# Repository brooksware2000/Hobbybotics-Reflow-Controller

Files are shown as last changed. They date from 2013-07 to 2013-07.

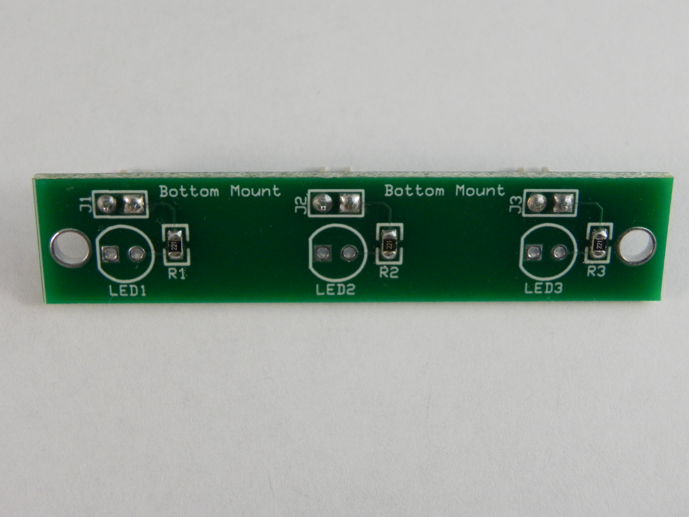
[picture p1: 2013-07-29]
Hardware/Hobbybotics LED Panel/Pictures/DSCN0549.JPG

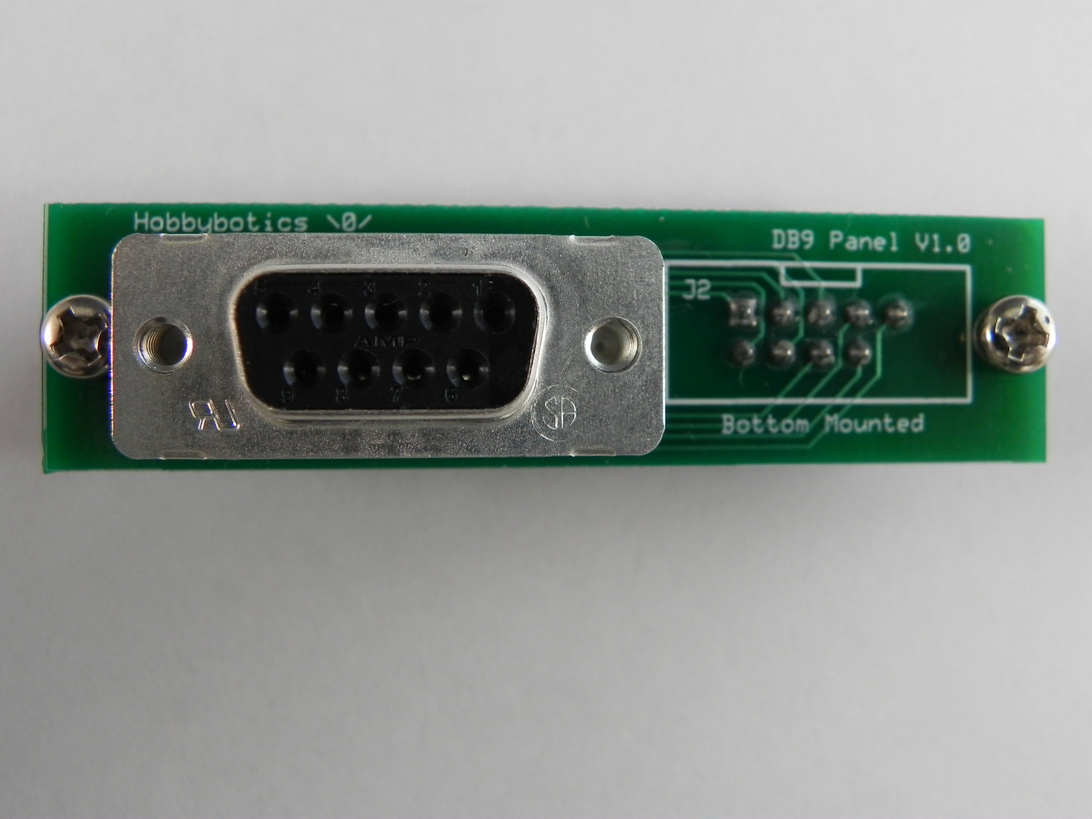
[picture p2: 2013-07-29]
Hardware/Hobbybotics DB9 Panel/Pictures/DSCN0542.JPG

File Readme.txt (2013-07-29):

The following files are for a reflow controller I designed to interface to a
common toaster oven.  The controller implements a PID routine and can be run
in manual mode or interfaced to a PC.

More information about this project can be found at the following links:

http://hobbybotics.com
http://hobbybotics.com/projects/hobbybotics-reflow-controller-v8-03/

28 July 2013 - Uploaded a revision to the firmware.  An error was identified in
the Bake routine which prevented it from working properly.  This has been fixed
in revision 5H.

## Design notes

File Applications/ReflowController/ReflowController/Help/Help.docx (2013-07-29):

Contents
Introduction | ............................................................ | 3
Welcome | ............................................................ | 3
License Agreement | ............................................................ | 3
Copyright and Trademarks | ............................................................ | 3
Application Window | ............................................................ | 4
Control Functions | ............................................................ | 4
Connect Button | ............................................................ | 4
Disconnect Button | ............................................................ | 4
Properties Button | ............................................................ | 4
Auxiliary 1 & 2 Button | ............................................................ | 4
Enable Logging Checkbox | ............................................................ | 5
Clear Data Button | ............................................................ | 5
Save Log File Button | ............................................................ | 5
Port Selection Field | ............................................................ | 5
Baud Rate Selection Field | ............................................................ | 5
Temperature Label | ............................................................ | 5
Set Point Temperature Label | ............................................................ | 5
Stage Remaining Time Label | ............................................................ | 5
Stage Label | ............................................................ | 5
Elapsed Time Label | ............................................................ | 5
Heater label | ............................................................ | 6
Auxiliary 1 Label | ............................................................ | 6
Auxiliary 2 Label | ............................................................ | 6
Log Data Grid | ............................................................ | 6
Log Data Chart | ............................................................ | 6
Menu Options | ............................................................ | 7
File Menu | ............................................................ | 7
View | ............................................................ | 7
Profile | ............................................................ | 7

Contents
Log File | ............................................................ | 8
Chart File | ............................................................ | 9
Chart Image | ............................................................ | 10
Save | ............................................................ | 11
Log File | ............................................................ | 11
Chart File | ............................................................ | 12
Chart Image | ............................................................ | 13
Page Setup | ............................................................ | 14
Print Preview | ............................................................ | 15
Print | ............................................................ | 16
Run Menu | ............................................................ | 17
Calibrate Oven | ............................................................ | 17
Start Reflow | ............................................................ | 18
Start Bake | ............................................................ | 19
Reset Controller | ............................................................ | 20
Configure Menu | ............................................................ | 21
Application Settings | ............................................................ | 21
Configure RTC | ............................................................ | 22
Create/Edit Profile | ............................................................ | 23
Upload Profile | ............................................................ | 24
Update Firmware | ............................................................ | 25
Open Programmer | ............................................................ | 26
Open Editor | ............................................................ | 27
Help Menu | ............................................................ | 28
About | ............................................................ | 28

Introduction

Welcome

The Reflow Controller application is an optional interface for the reflow controller hardware. The software is designed to allow computer control of the reflow controller and log reflow sessions for later viewing and editing.

License Agreement

This agreement shall govern the use of this software by the user of the Software Package. The user is granted the right to use, modify, and redistribute this Software Package as he or she wishes. The developer of this software will not assume any responsibility for the misuse of this software or any damage that may result from use of this software.

Copyright and Trademarks

Hobbybotics reserves the right to modify this license agreement at any time.

Application Window

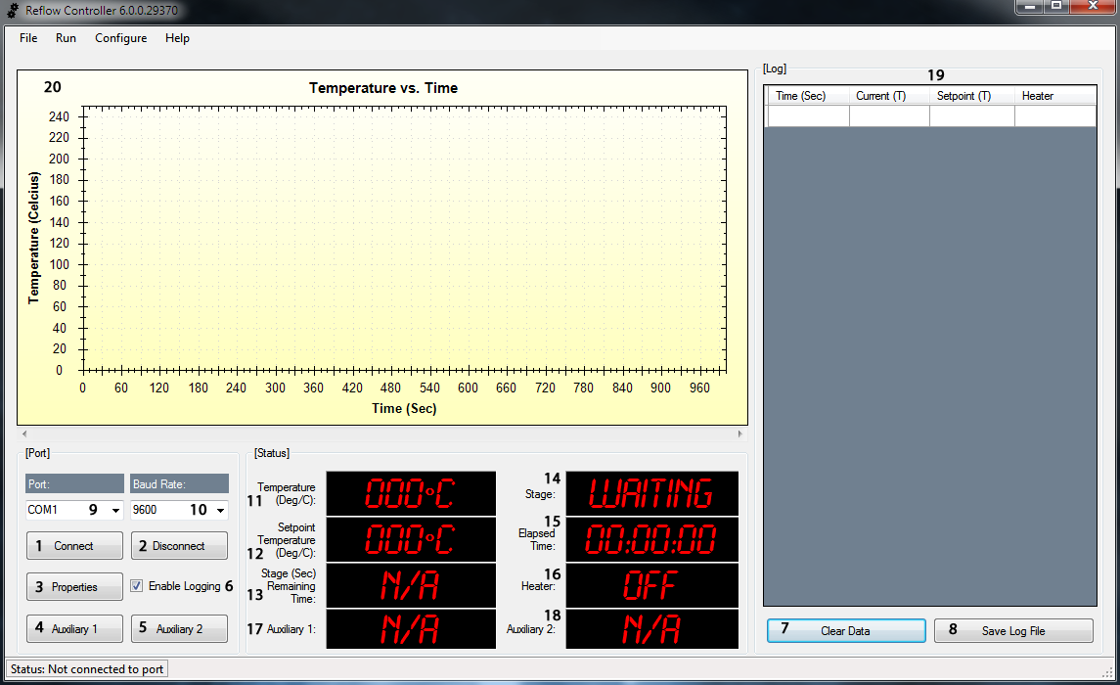
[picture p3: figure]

Control Functions

1. Connect Button

This button establishes a connection to the selected serial port at the selected baud rate if available ports are detected.

2. Disconnect Button

This button disconnects from the serial port.

3. Properties Button

This button opens the device manager applet so that the serial port properties may be viewed or edited.

4. Auxiliary 1 Button

This button will connect or disconnect the device attached to the auxiliary jack.

5. Auxiliary 2 Button

This button will connect or disconnect the device attached to the auxiliary jack.

6. Enable Logging Checkbox

This checkbox will enable or disable data logging.

7. Clear Data Button

This button will clear any data contained in the data grid.

8. Save Log File Button

This button will save a log file of data from the data grid to a file compatible with Microsoft Excel or any Excel compatible spreadsheet. The created file can also be opened with a text editor.

9. Port Selection

This field is loaded with all detected serial ports and allows a port to be selected for connection. The propertied button should be used to ensure the selected port matches the port the reflow controller is connected to.

10. Baud Rate Selection

This field is loaded with available baud rates. The default baud rate for the reflow controller is 9600 baud. The selected baud rate needs to match this setting to ensure proper communication.

11. Temperature Label

This label displays the current temperature measurement.

12. Set Point Temperature Label

This label displays the set point temperature value.

13. Stage Remaining Time Label

This label displays the remaining time for each stage (Preheat, Soak, Heating, Reflow, Cool Down and Bake).

14. Stage Label

This label displays the current stage (Preheat, Soak, Heating, Reflow, Cool Down and Bake).

15. Elapsed Time Label

This label displays the total time the process is taking.

16. Heater Label

This label displays the on/off state of the oven heater relay.

17. Auxiliary 1 Label

This label displays the on/off state of the auxiliary 1 device.

18. Auxiliary 2 Label

This label displays the on/off state of the auxiliary 2 device.

19. Log Data Grid

This data grid captures the time (seconds), current temperature (Celsius), set point temperature (Celsius) and heater on/off state of the reflow process. This data can be exported to an Excel compatible file.

20. Log Data Chart

This graphical chart plots the time (seconds) and current temperature (Celsius) of the reflow process as a line graph. This chart can be saved as an image, saved as a data file or printed.

Menu Options

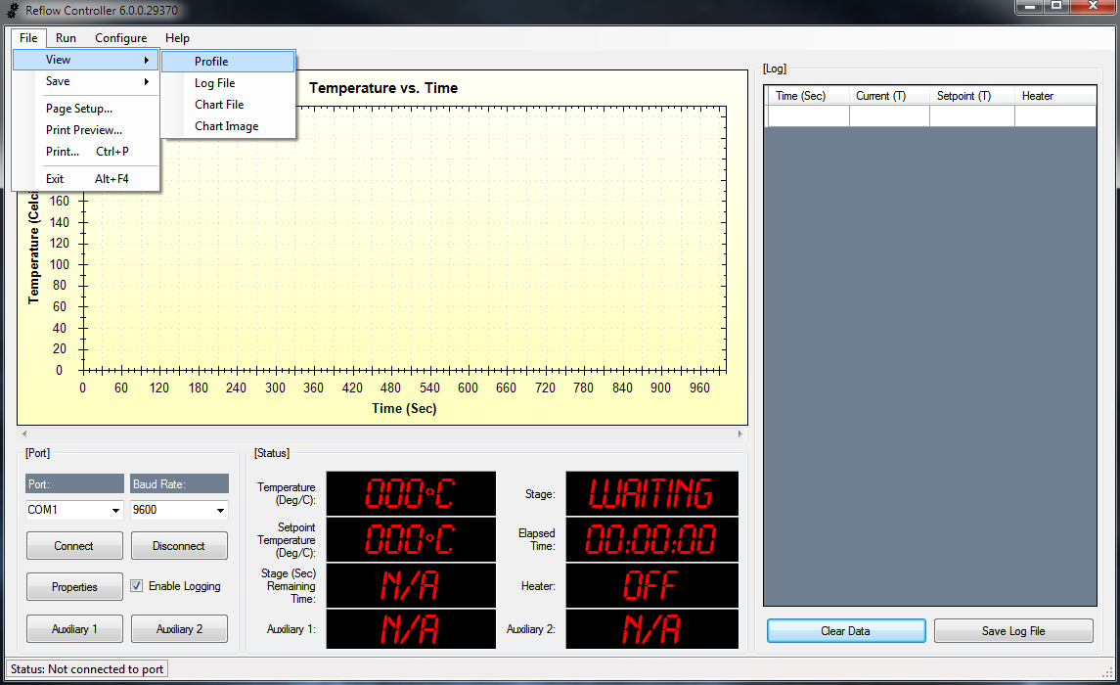
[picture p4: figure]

File Menu

- View Profile

This menu option opens a reflow profile for viewing and editing within the default text editor.

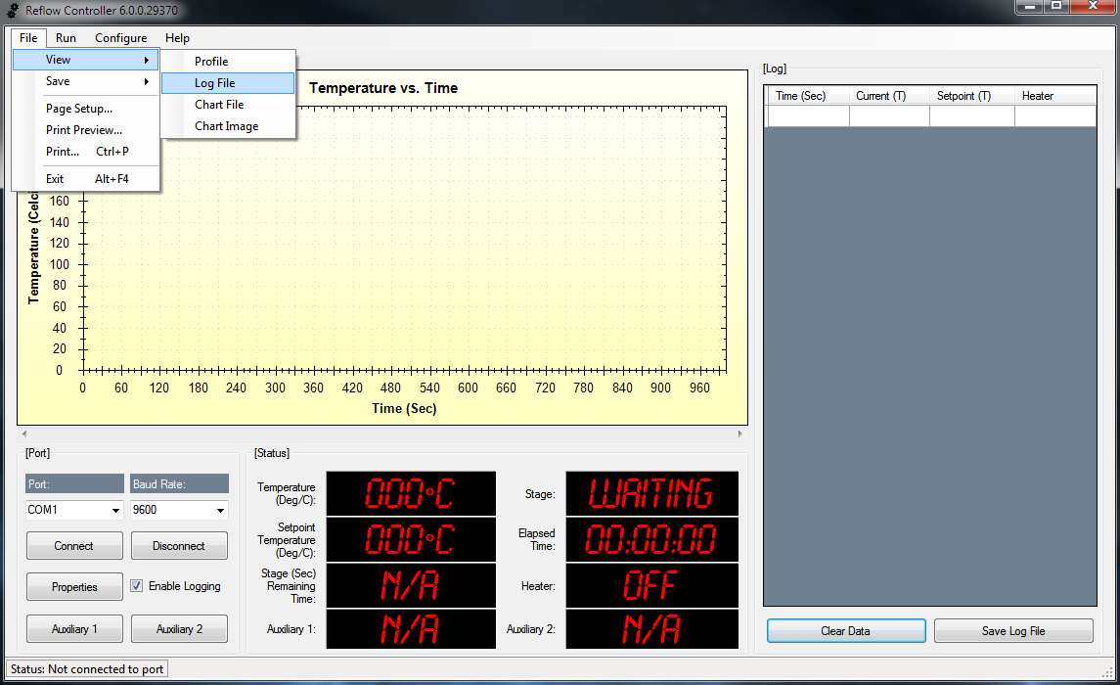
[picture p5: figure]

- View Log File

This menu option opens a log file for viewing and editing within Microsoft Excel. A compatible spreadsheet application or text editor can be used to view and edit a log file.

- View Chart File

This menu option opens a chart file for viewing within the reflow application.

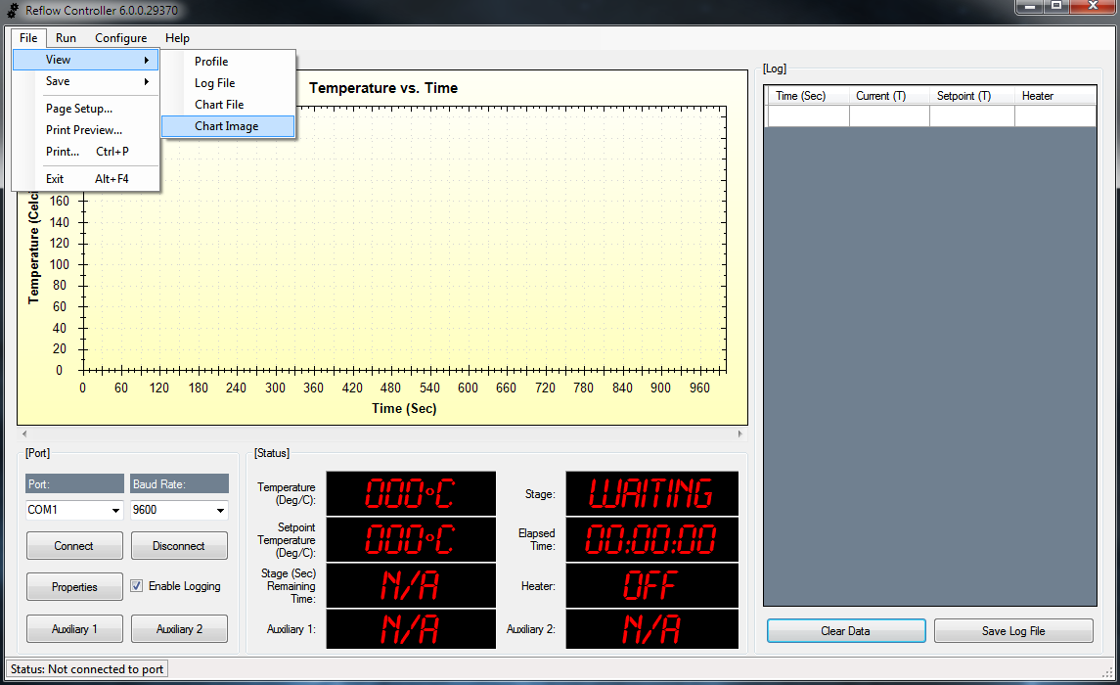
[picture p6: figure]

- View Chart Image

This menu option opens a chart image for viewing and editing with the default image application.

- Save Log File

This menu option saves a reflow session to a log file for viewing and editing in Microsoft Excel. A compatible spreadsheet application or text editor can be used to view and edit a log file.

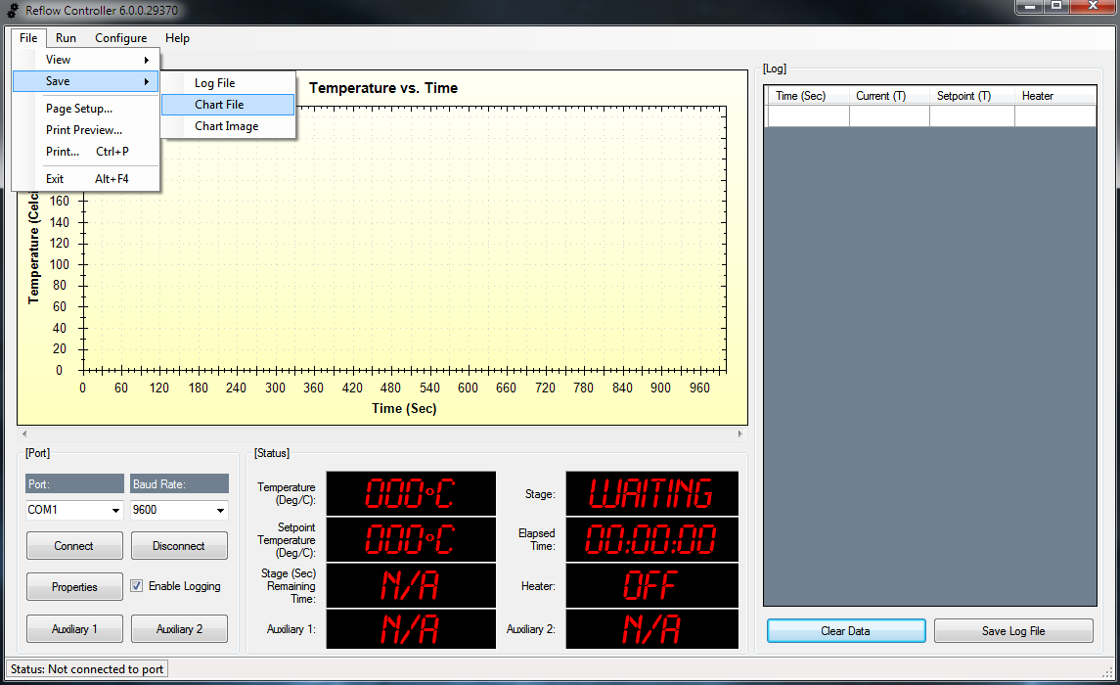
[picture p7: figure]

- Save Chart File

This menu option saves the graphical chart data to a chart file for viewing within the reflow application.

- Save Chart Image

This menu option saves a chart image to a file for viewing and editing with the default image application.

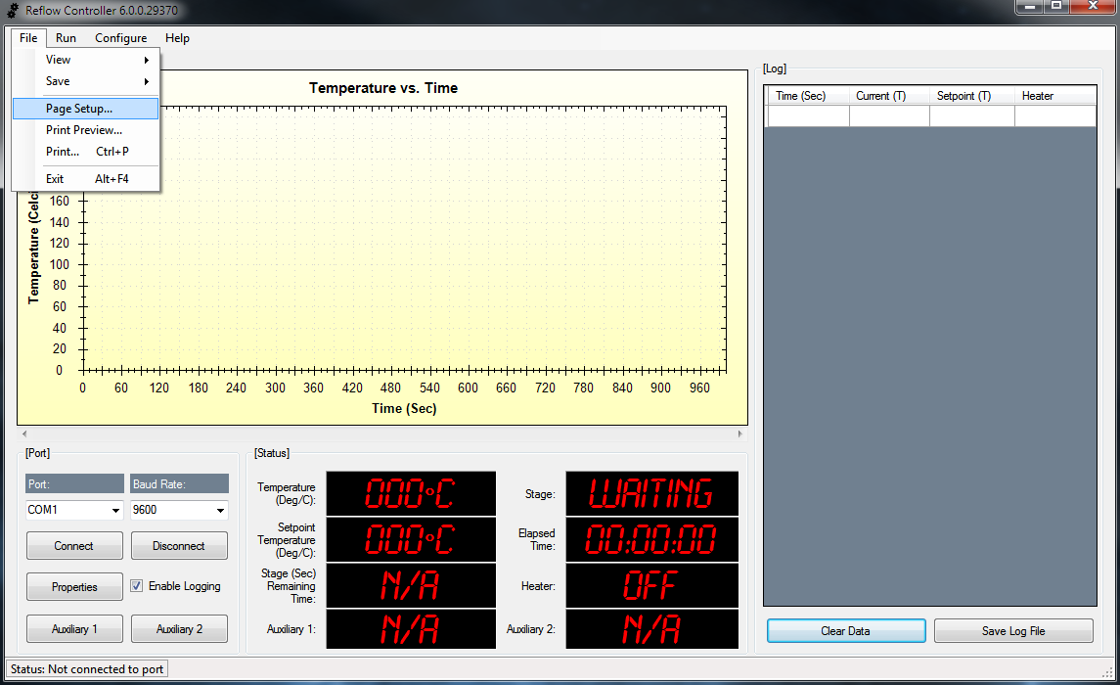
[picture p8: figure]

- Page Setup

This menu option allows page settings to be adjusted for printing.

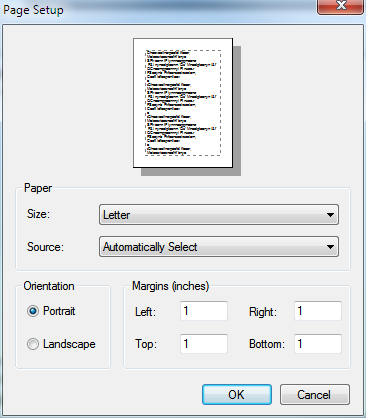
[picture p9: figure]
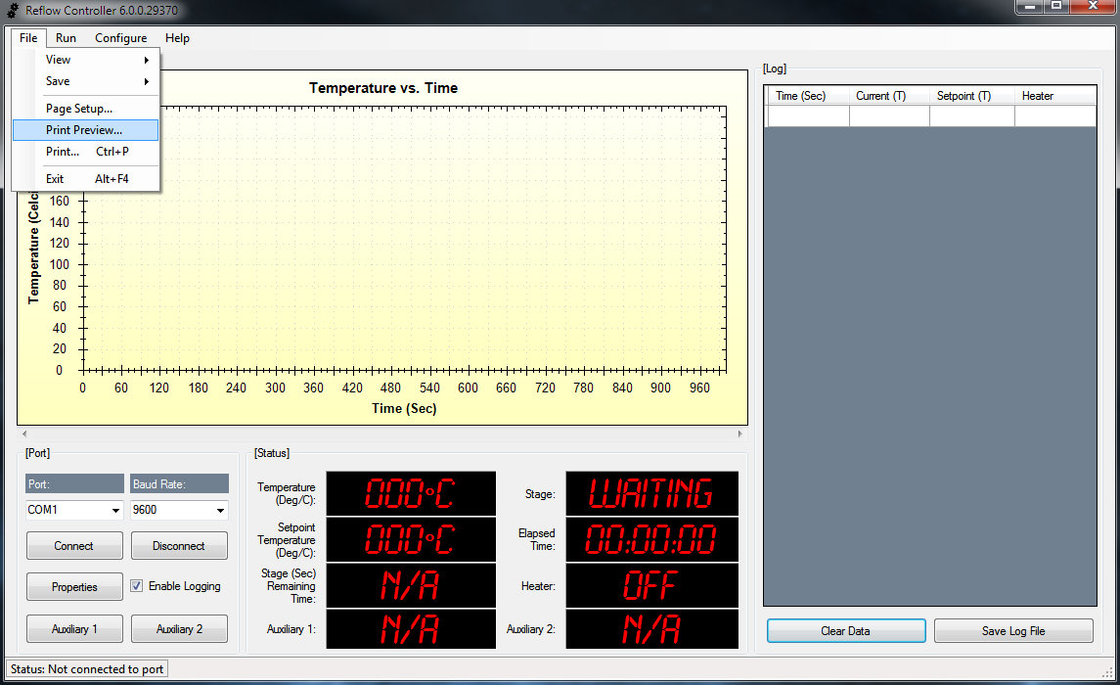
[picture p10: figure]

- Print Preview

This menu option shows a print preview of the chart image.

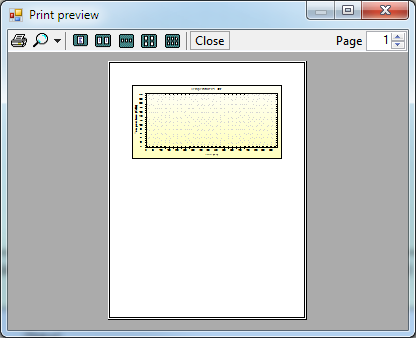
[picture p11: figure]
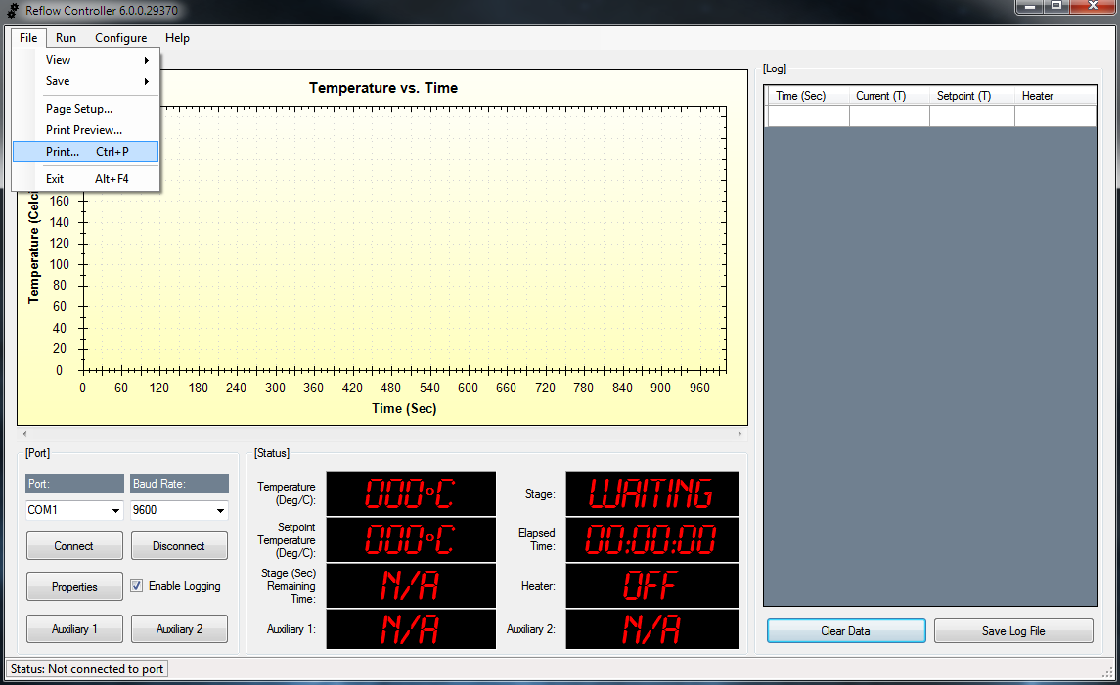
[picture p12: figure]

- Print

This menu option prints a chart image.

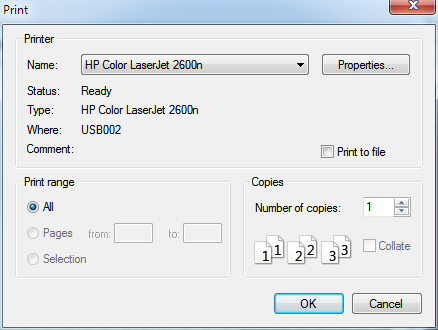
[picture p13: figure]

Run Menu

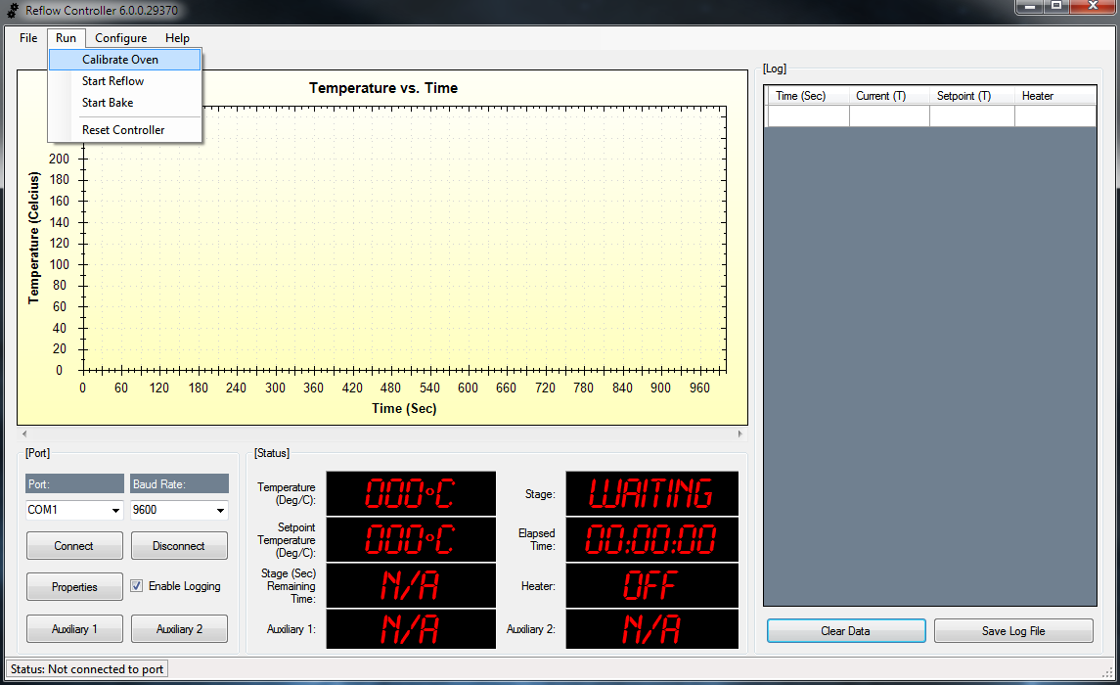
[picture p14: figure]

- Calibrate Oven

This menu option starts the calibration function of the reflow oven. The oven is heated up to 100 degrees Celsius and turned off. The reflow controller measures the amount of temperature drift above 100 degrees Celsius and stores that value as the oven overshoot value. The overshoot value is used during a reflow process to apply hysteresis.

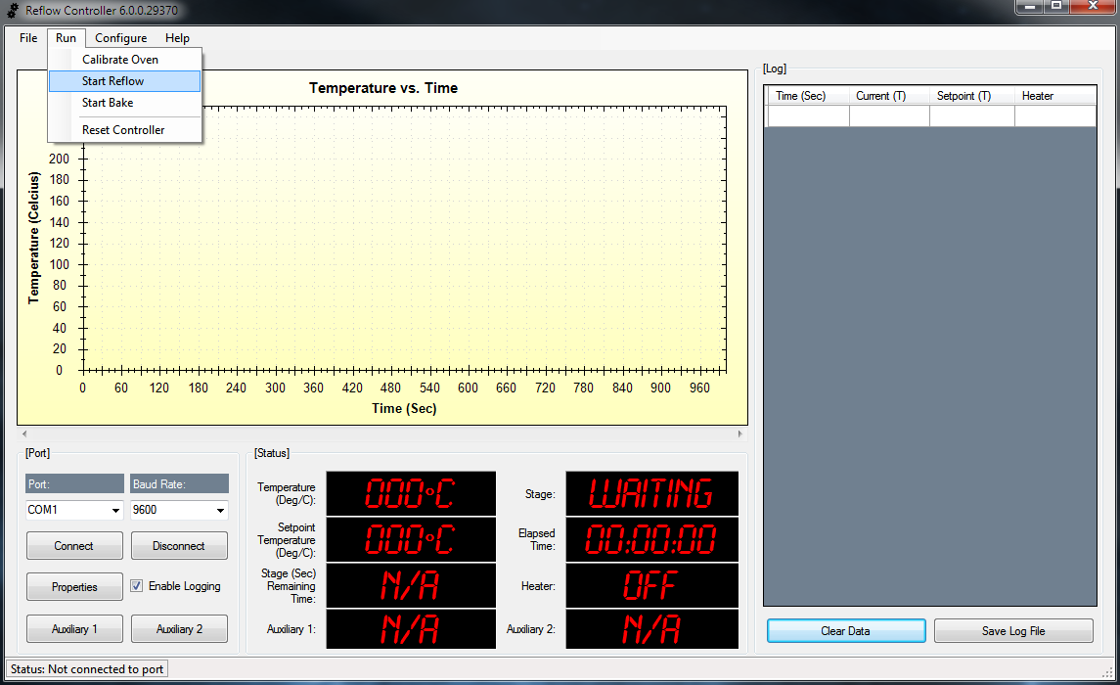
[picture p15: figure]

- Start Reflow

This menu option starts the reflow process. This process is used to solder components on a printed circuit board.

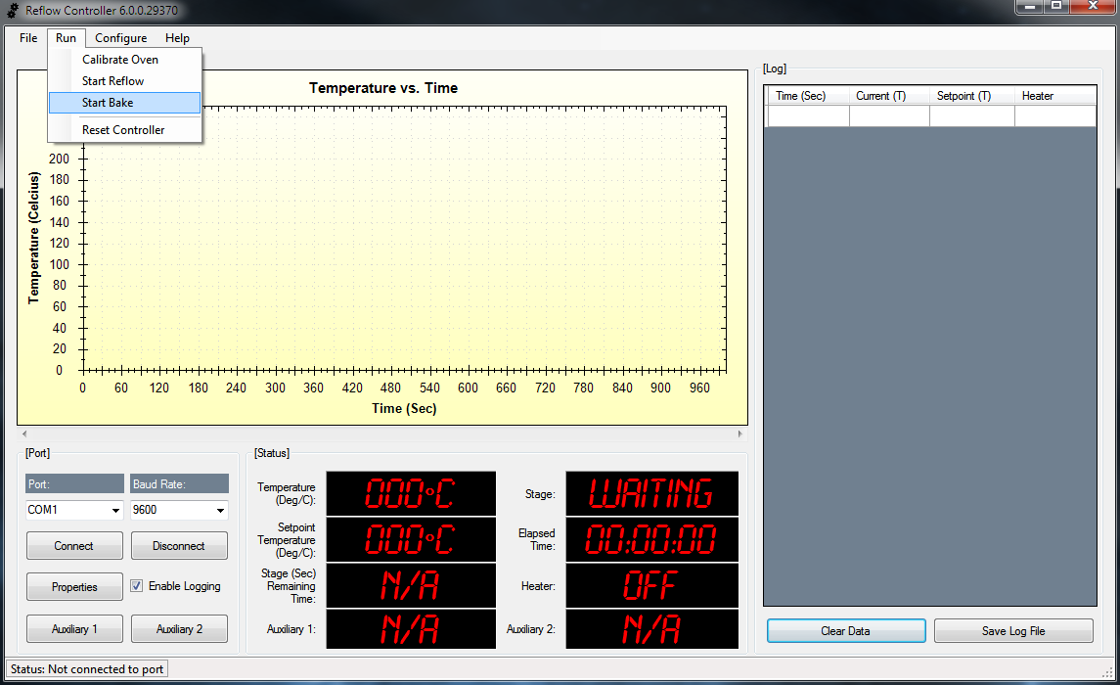
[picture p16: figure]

- Start Bake

This menu option starts the baking process. This process is used for removing moisture from components.

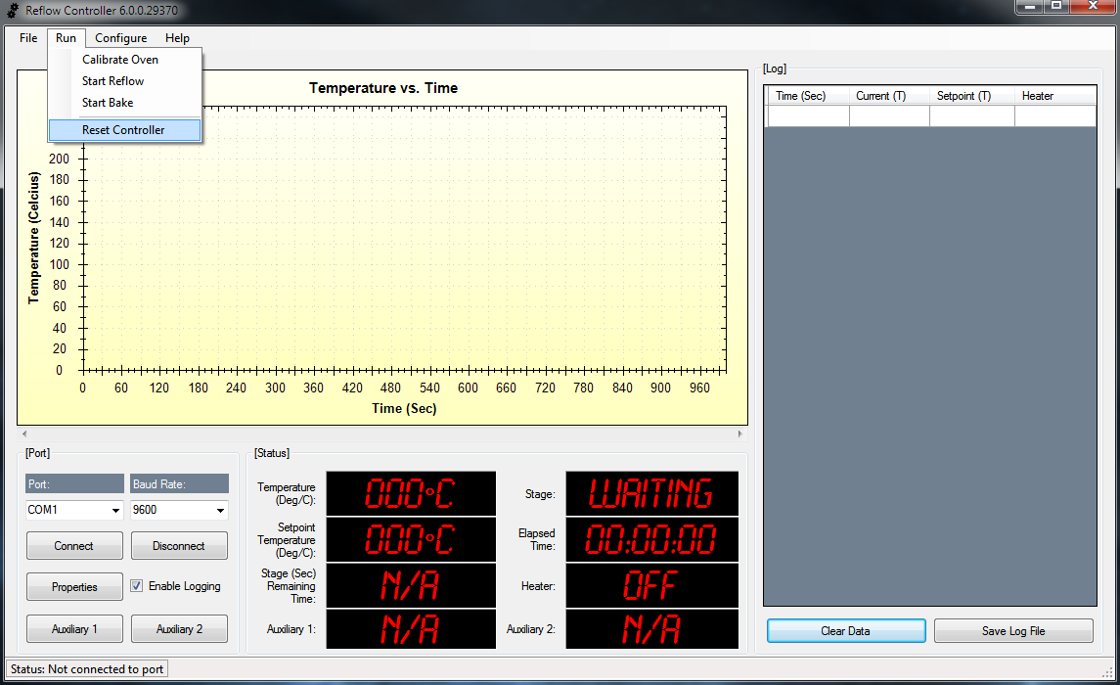
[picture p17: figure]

- Reset Controller

This menu option reboots the reflow controller.

Configure Menu

- Application Settings

This menu option opens a form where the default firmware loader, hardware programmer and program editor can be set.

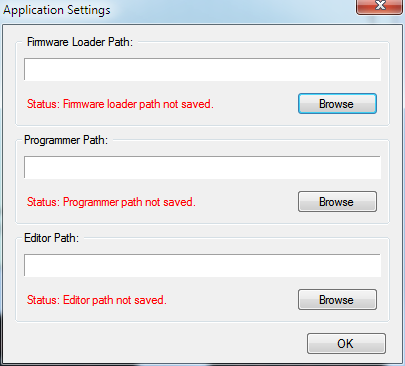
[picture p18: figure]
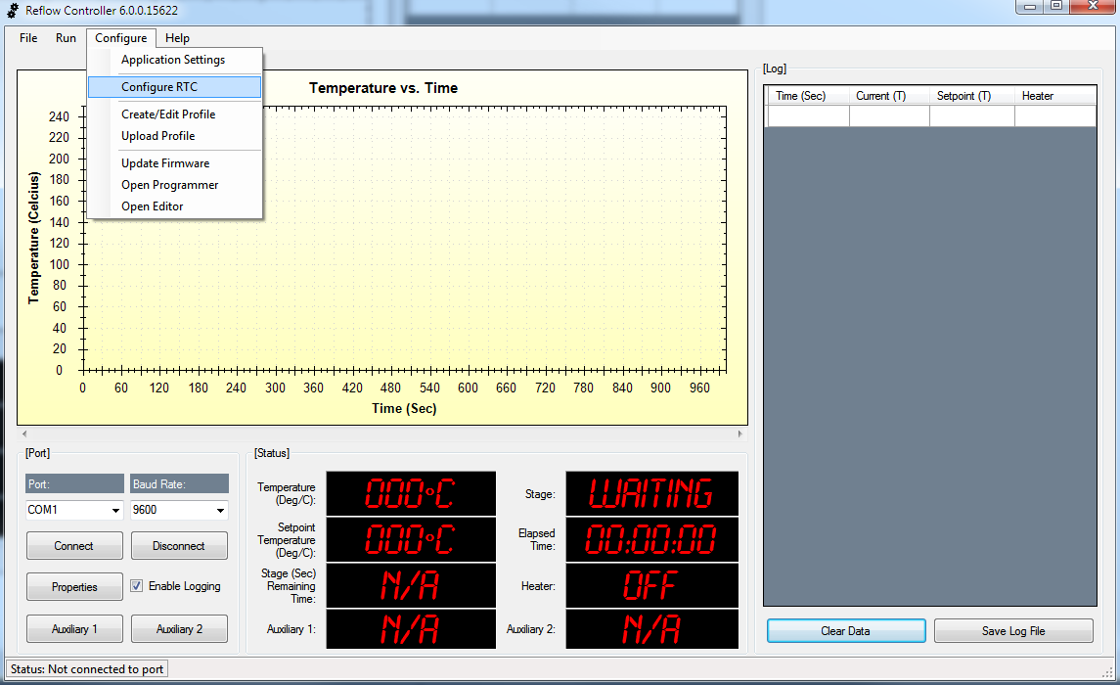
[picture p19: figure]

- Configure RTC

This menu option configures the optional real time clock (RTC) attached to the reflow controller. This option only needs to be selected for an initial configuration of the RTC.

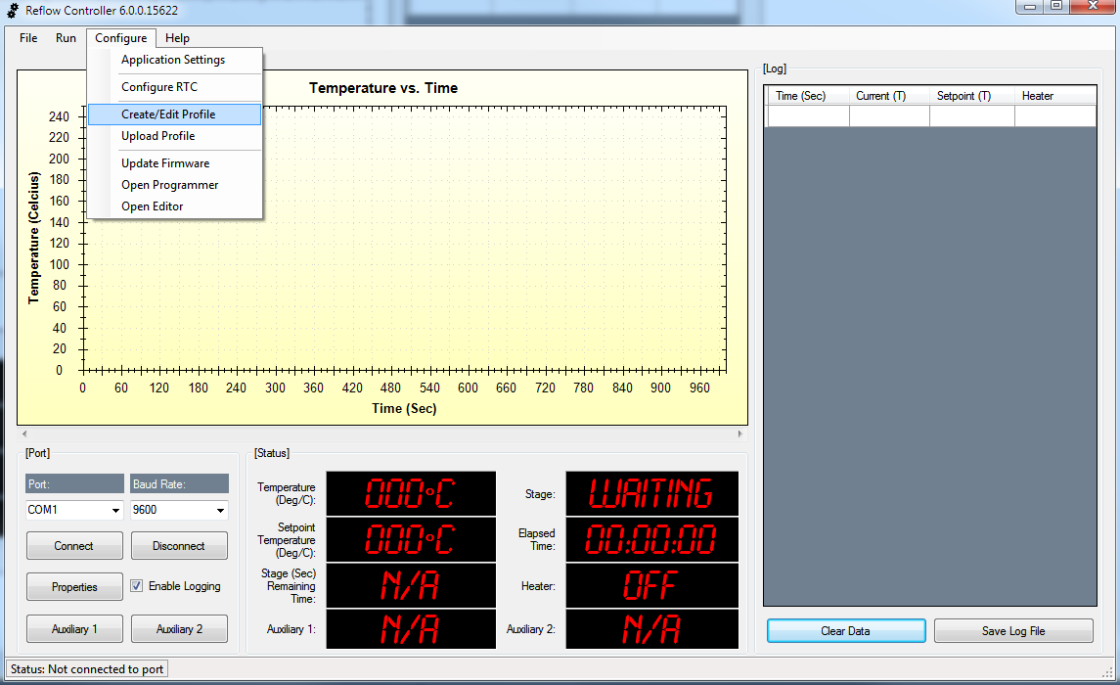
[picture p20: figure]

- Create/Edit Profile

This menu option opens a form where a reflow profile can be created or edited.

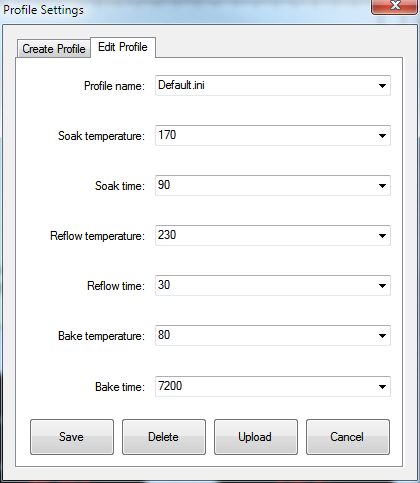
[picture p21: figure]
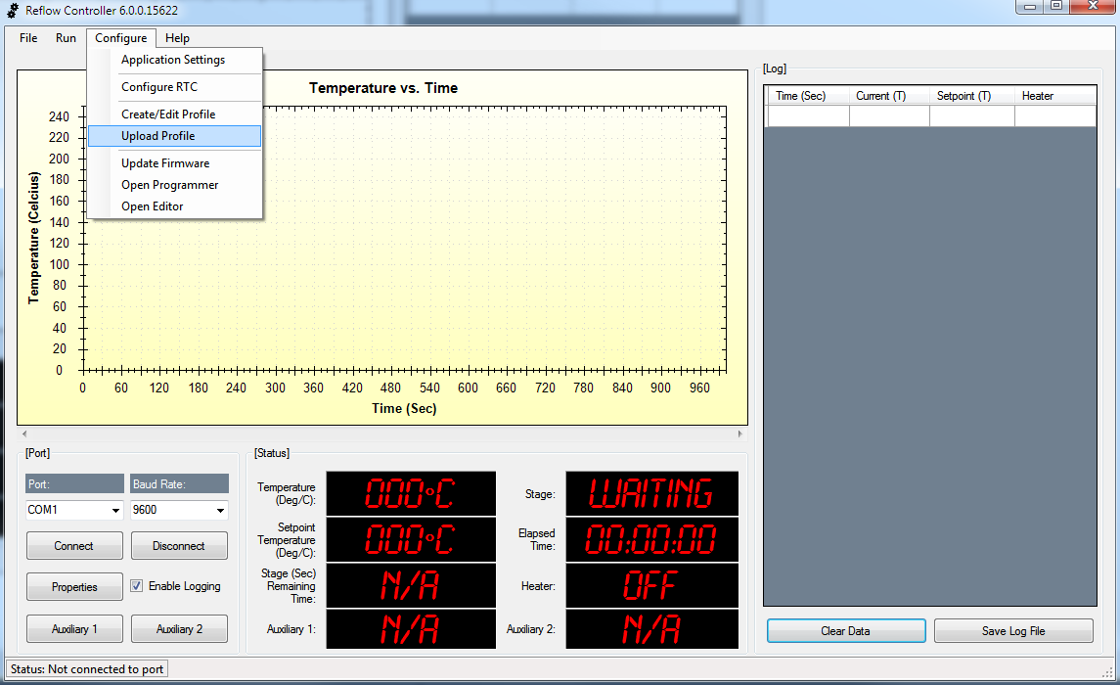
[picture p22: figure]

- Upload Profile

This menu option uploads a selected profile to the reflow controller.

- Update Firmware

This menu option opens the default firmware loader. The firmware loader is used to re-flash the reflow controller over the serial port without needing a hardware programmer. The following error message will be displayed if no firmware loader application is found:

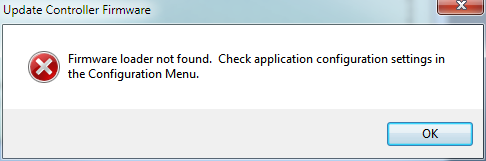
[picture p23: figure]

The firmware loader application is optional and not included with the reflow application.

- Open Programmer

This menu option opens the default program loader. The program loader is used to load hex files onto the reflow controller without using a bootloader. The following error message will be displayed if no programmer application is found:

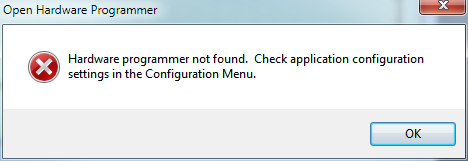
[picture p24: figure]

The programmer application is optional and not included with the reflow application.

- Open Editor

This menu option opens the default program editor application. The program editor is used to edit code that will be compiled into a hex file and loaded onto the reflow controller using a programmer. The following error message will be displayed if no program editor application is found:

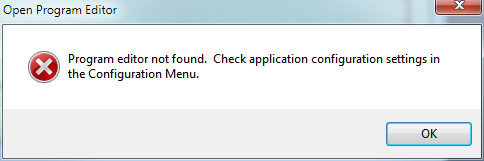
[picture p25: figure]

The program editor is optional and not included with the reflow application.

Help Menu

- About

This menu option opens a form that displays information about the current version of the reflow controller application.

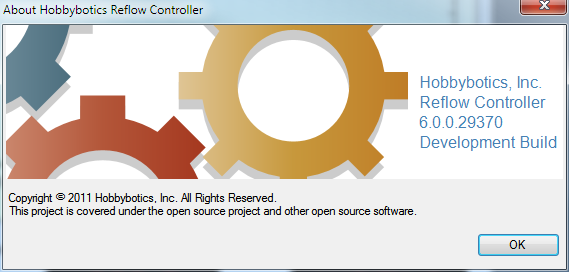
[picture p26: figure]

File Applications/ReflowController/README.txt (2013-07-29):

The application uses specific fonts that need to be installed in order for text to appear correctly.
These fonts can be found in the "Fonts" folder.

The project makes use of three class libraries that have been compiled into DLL files.  These are:

- DS1307Lib: Interface class to setup a DS1307 RTC (This class has not been tested or debugged)
- FileLib:   Class for file and *.ini
- SerialLib: Class for controller functionality.  Allows Reflow board to be controlled through a serial connection

this project also makes use of the ZedGraph control.  This control is already contained as part of the project and
provides easy functionality for a graphing reflow sessions.  I do not believe the author supports this control any
longer however, it is still available on the web.

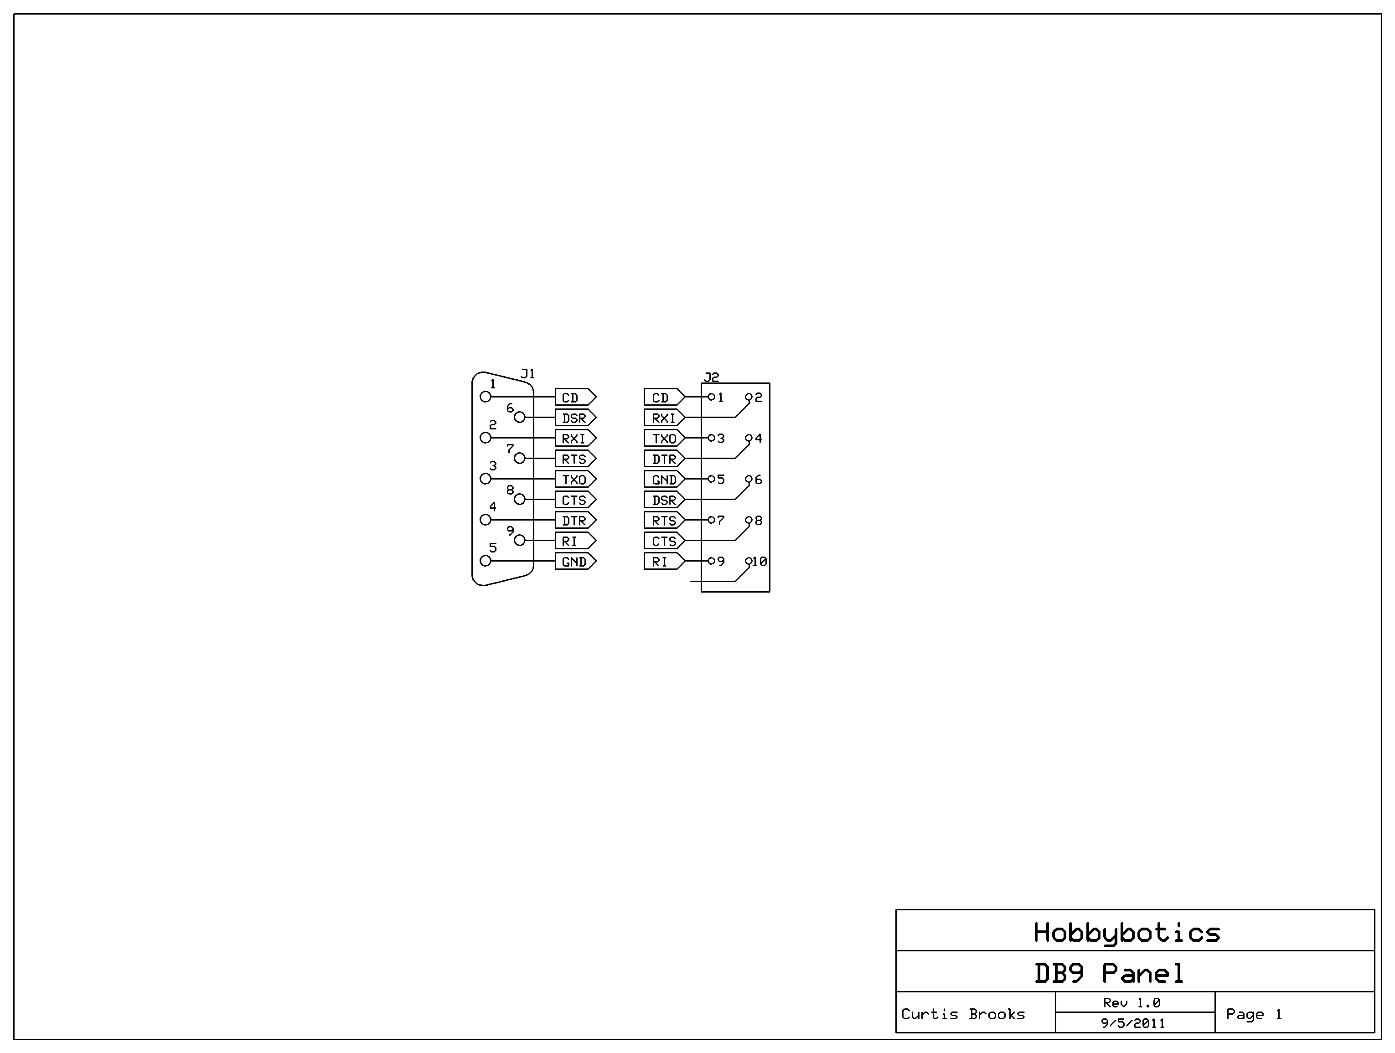
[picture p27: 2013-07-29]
Hardware/Hobbybotics DB9 Panel/Pictures/Hobbybotics DB9 Panel V1.00 - Schematic_3060x2310.png

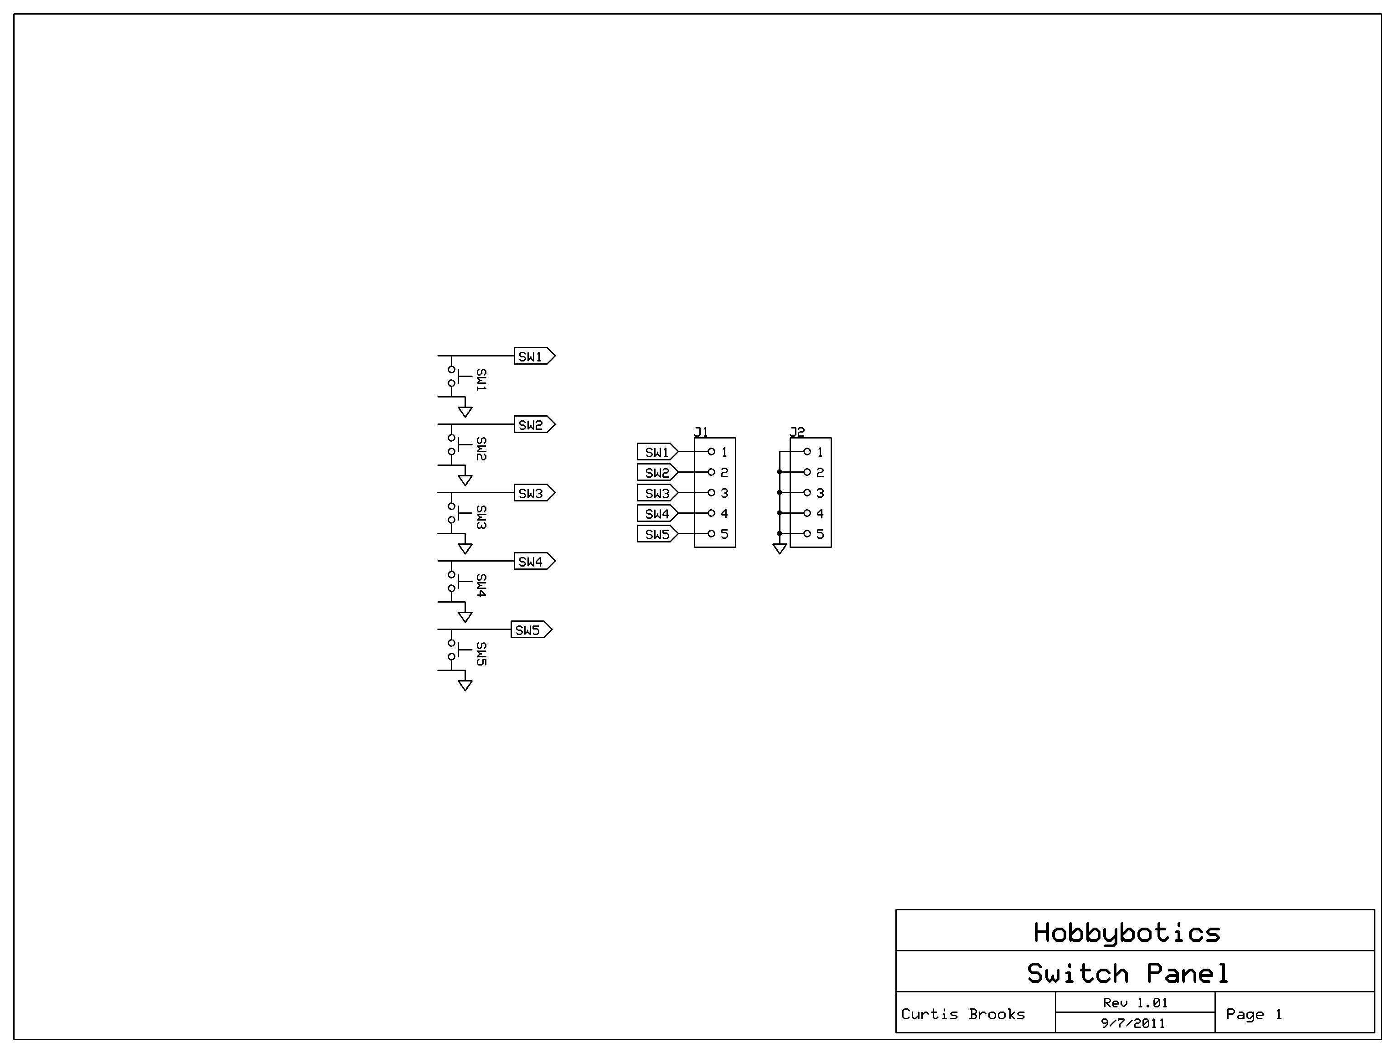
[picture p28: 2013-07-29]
Hardware/HobbyboticsSwitch Panel/Pictures/Hobbybotics Switch Panel V1.01 - Schematic_3060x2310.png

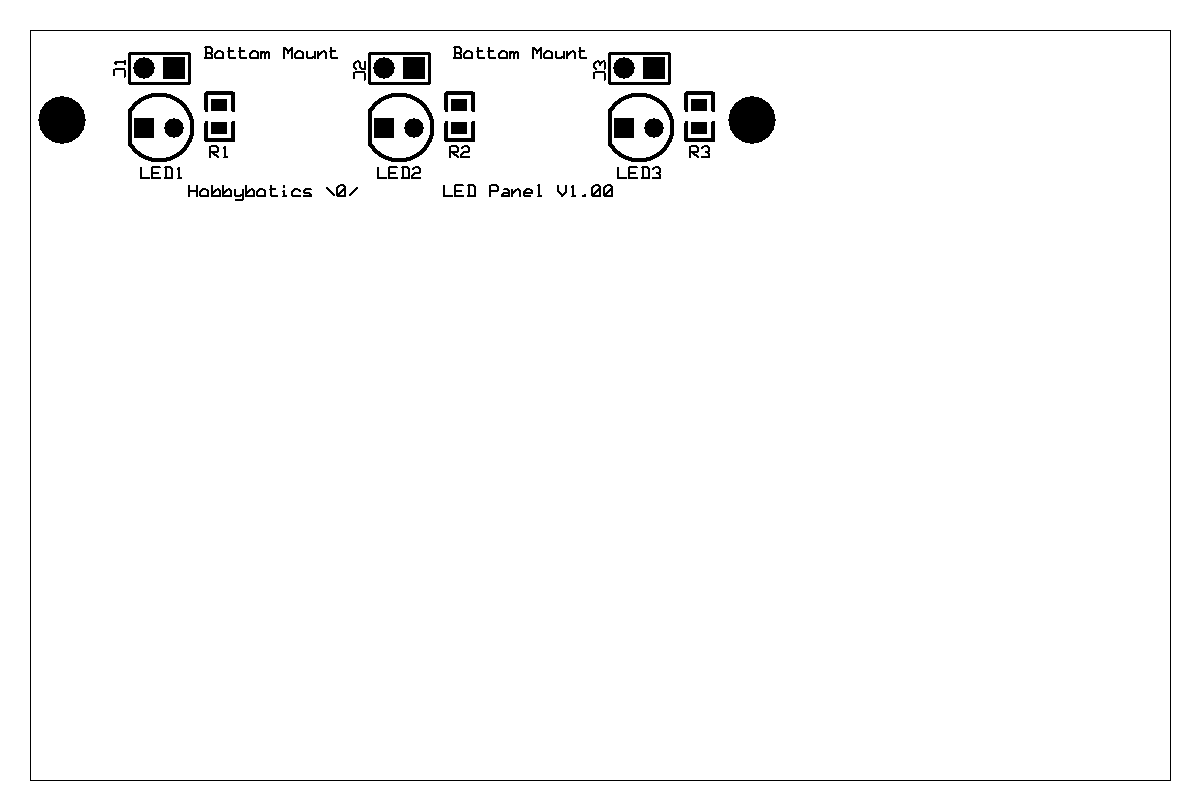
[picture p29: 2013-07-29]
Hardware/Hobbybotics LED Panel/Pictures/Hobbybotics LED Panel V1.00_1200x810.png

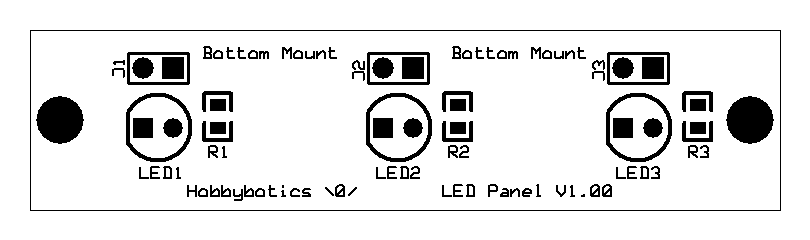
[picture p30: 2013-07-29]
Hardware/Hobbybotics LED Panel/Pictures/Hobbybotics LED Panel V1.00 (Production)_810x240.png

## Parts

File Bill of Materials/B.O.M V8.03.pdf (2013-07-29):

B.O.M V8.03.txt | Thursday, May 31, 2012 9:06 PM
BZ1 Buzzer Mouser 810-PS1240P02BT
C1 0.1uF Mouser 80-C0805C104K3R
C2 1uF Mouser 810-C2012Y5V1C105Z-2
C3 1uF Mouser 810-C2012Y5V1C105Z-2 C4 1uF Mouser 810-C2012Y5V1C105Z-2 C5 1uF Mouser 810-C2012Y5V1C105Z-2 C6 0.1uF Mouser 80-C0805C104K3R C7 10uF Mouser 667-EEE-FP1E100AR C8 0.1uF Mouser 80-C0805C104K3R C9 10uF Mouser 667-EEE-FP1E100AR C10 0.1uF Mouser 80-C0805C104K3R C11 0.1uF Mouser 80-C0805C104K3R
C12 0.1uF Mouser 80-C0805C104K3R
D1 1N5819 Mouser 621-1N5819HW-F
J1 2x5 Header Mouser 649-52601-S10-4LF
J2 3P Header
J3 2P Buckled Connector Mouser 571-5-103634-1 J4 6P Right Angle Header Mouser 538-22-28-8060 J5 2P Buckled Connector Mouser 571-5-103634-1 J6 2P Buckled Connector Mouser 571-5-103634-1 J7 2P Buckled Connector Mouser 571-5-103634-1 J8 2P Buckled Connector Mouser 571-5-103634-1 J9 2x5 Shrouded Header Mouser 649-52601-S10-4LF J10 6P Connector Mouser 571-5-534237-4
J11 6P Connector Mouser 571-5-534237-4
J12 6P Connector Mouser 571-5-534237-4
J13 6P Connector Mouser 571-5-534237-4 J14 3P Header
JP1 Jumper Block
JP2 Jumper Block
LCD1 4x20 HD44780 Connector Mouser 538-22-28-8060 LED1 0805 LED Mouser 645-598-8110-107F
Q1 MMBT2222A Mouser 512-MMBT2222AD87Z
R1 10k Mouser 71-CRCW0805-10K-E3
R2 10k Mouser 71-CRCW0805-10K-E3
R3 10k Mouser 71-CRCW0805-10K-E3
R4 10k Mouser 71-CRCW0805-10K-E3 R5 10k Mouser 71-CRCW0805-10K-E3 R6 10k Mouser 71-CRCW0805-10K-E3 R7 10k Mouser 81-PVZ3A103C01B00 R8 15 Mouser 71-CRCW0805-15-E3 R9 1k Mouser 260-1.0K-RC
R10 10k Mouser 71-CRCW0805-10K-E3
R11 1k Mouser 260-1.0K-RC
R12 10k Mouser 71-CRCW0805-10K-E3
SW1 2P Buckled Connector Mouser 571-5-103634-1 SW2 2P Buckled Connector Mouser 571-5-103634-1 SW3 2P Buckled Connector Mouser 571-5-103634-1 SW4 2P Buckled Connector Mouser 571-5-103634-1 SW5 2P Buckled Connector Mouser 571-5-103634-1 SW6 SPST
SW7 SPST N.O. Mouser 612-TL3302A-260
SW8 2P Buckled Connector Mouser 571-5-103634-1 U1 PIC16F877A Mouser 579-PIC16F887-I/P

-1-

B.O.M V8.03.txt | Thursday, May 31, 2012 9:06 PM
U2 MAX6675 Mouser 700-MAX6675ISA
U3 MAX3232 Sparkfun COM-00589
VR1 AP1117 Mouser 621-AP1117E50G-13
X1 20MHz Sparkfun COM-00092

-2-

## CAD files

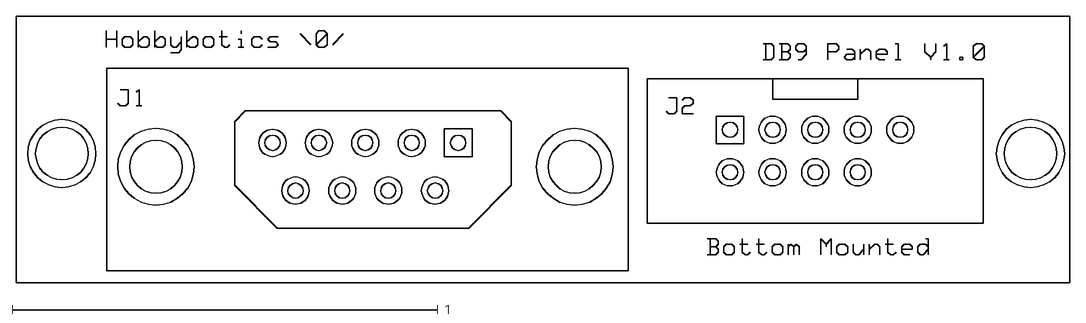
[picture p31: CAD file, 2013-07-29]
Hardware/Hobbybotics DB9 Panel/DXF/Hobbybotics DB9 Panel V1.00 (Production).dxf
2.48 x 0.625

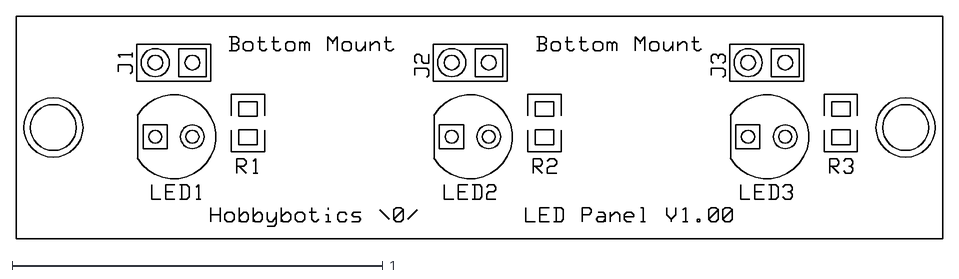
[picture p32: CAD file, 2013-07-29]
Hardware/Hobbybotics LED Panel/DXF/Hobbybotics LED Panel V1.00 (Production).dxf
2.50 x 0.6

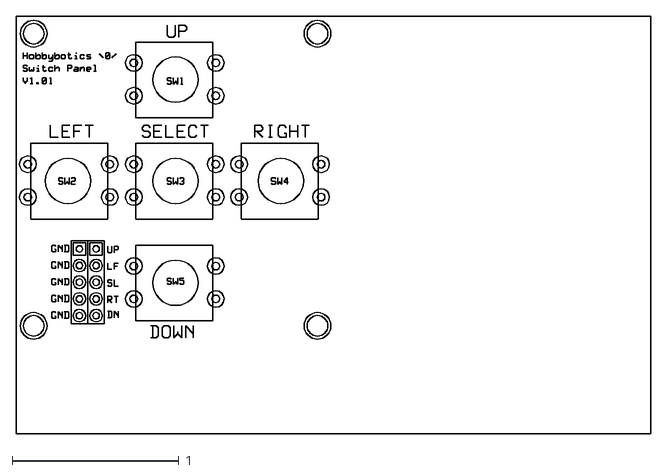
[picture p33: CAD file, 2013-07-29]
Hardware/HobbyboticsSwitch Panel/DXF/Hobbybotics Switch Panel V1.01.dxf
3.80 x 2.50

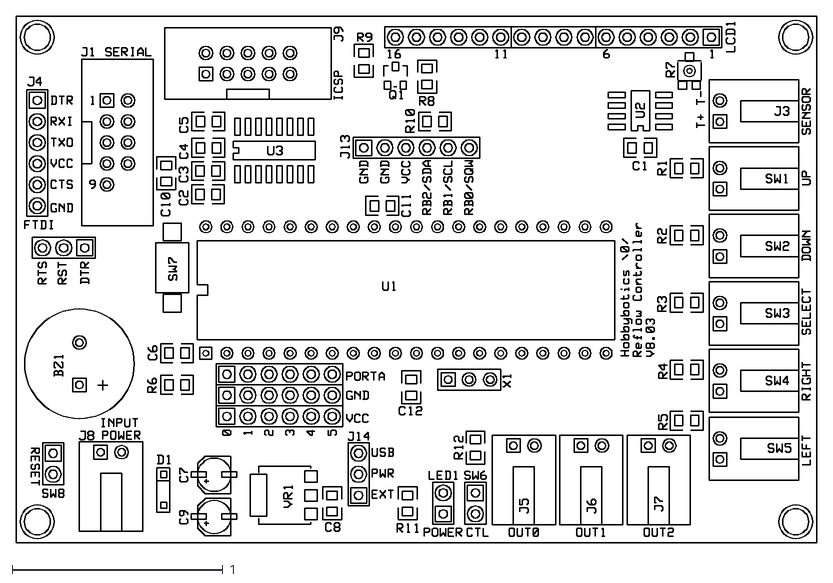
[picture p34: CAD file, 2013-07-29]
Hardware/Main Board/Reflow Controller V8.03.dxf
3.80 x 2.50

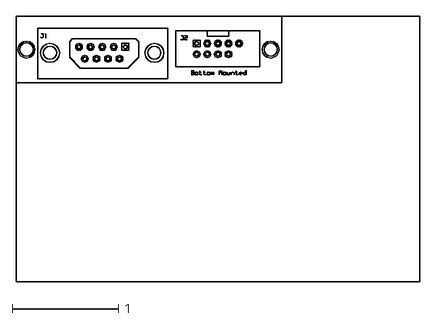
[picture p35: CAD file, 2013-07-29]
Hardware/Hobbybotics DB9 Panel/DXF/Hobbybotics DB9 Panel V1.00.dxf
3.80 x 2.50

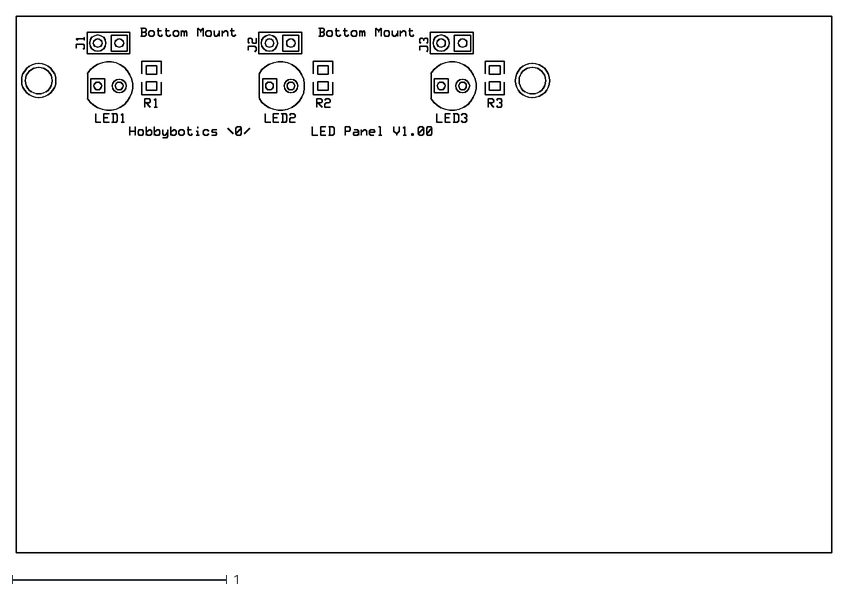
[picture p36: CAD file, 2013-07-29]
Hardware/Hobbybotics LED Panel/DXF/Hobbybotics LED Panel V1.00.dxf
3.80 x 2.50

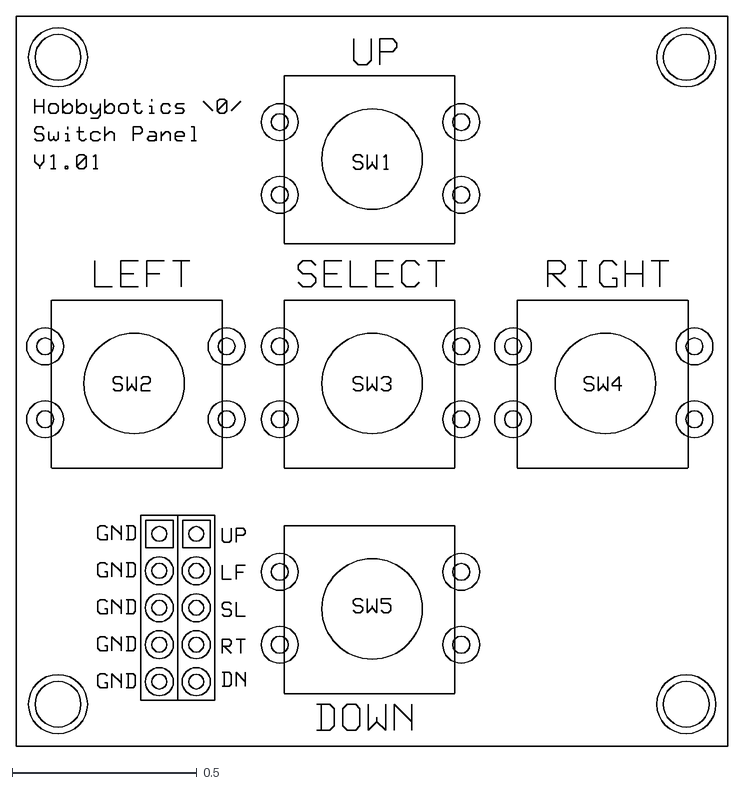
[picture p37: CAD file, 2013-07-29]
Hardware/HobbyboticsSwitch Panel/DXF/Hobbybotics Switch Panel V1.01 (Production).dxf
1.93 x 1.98

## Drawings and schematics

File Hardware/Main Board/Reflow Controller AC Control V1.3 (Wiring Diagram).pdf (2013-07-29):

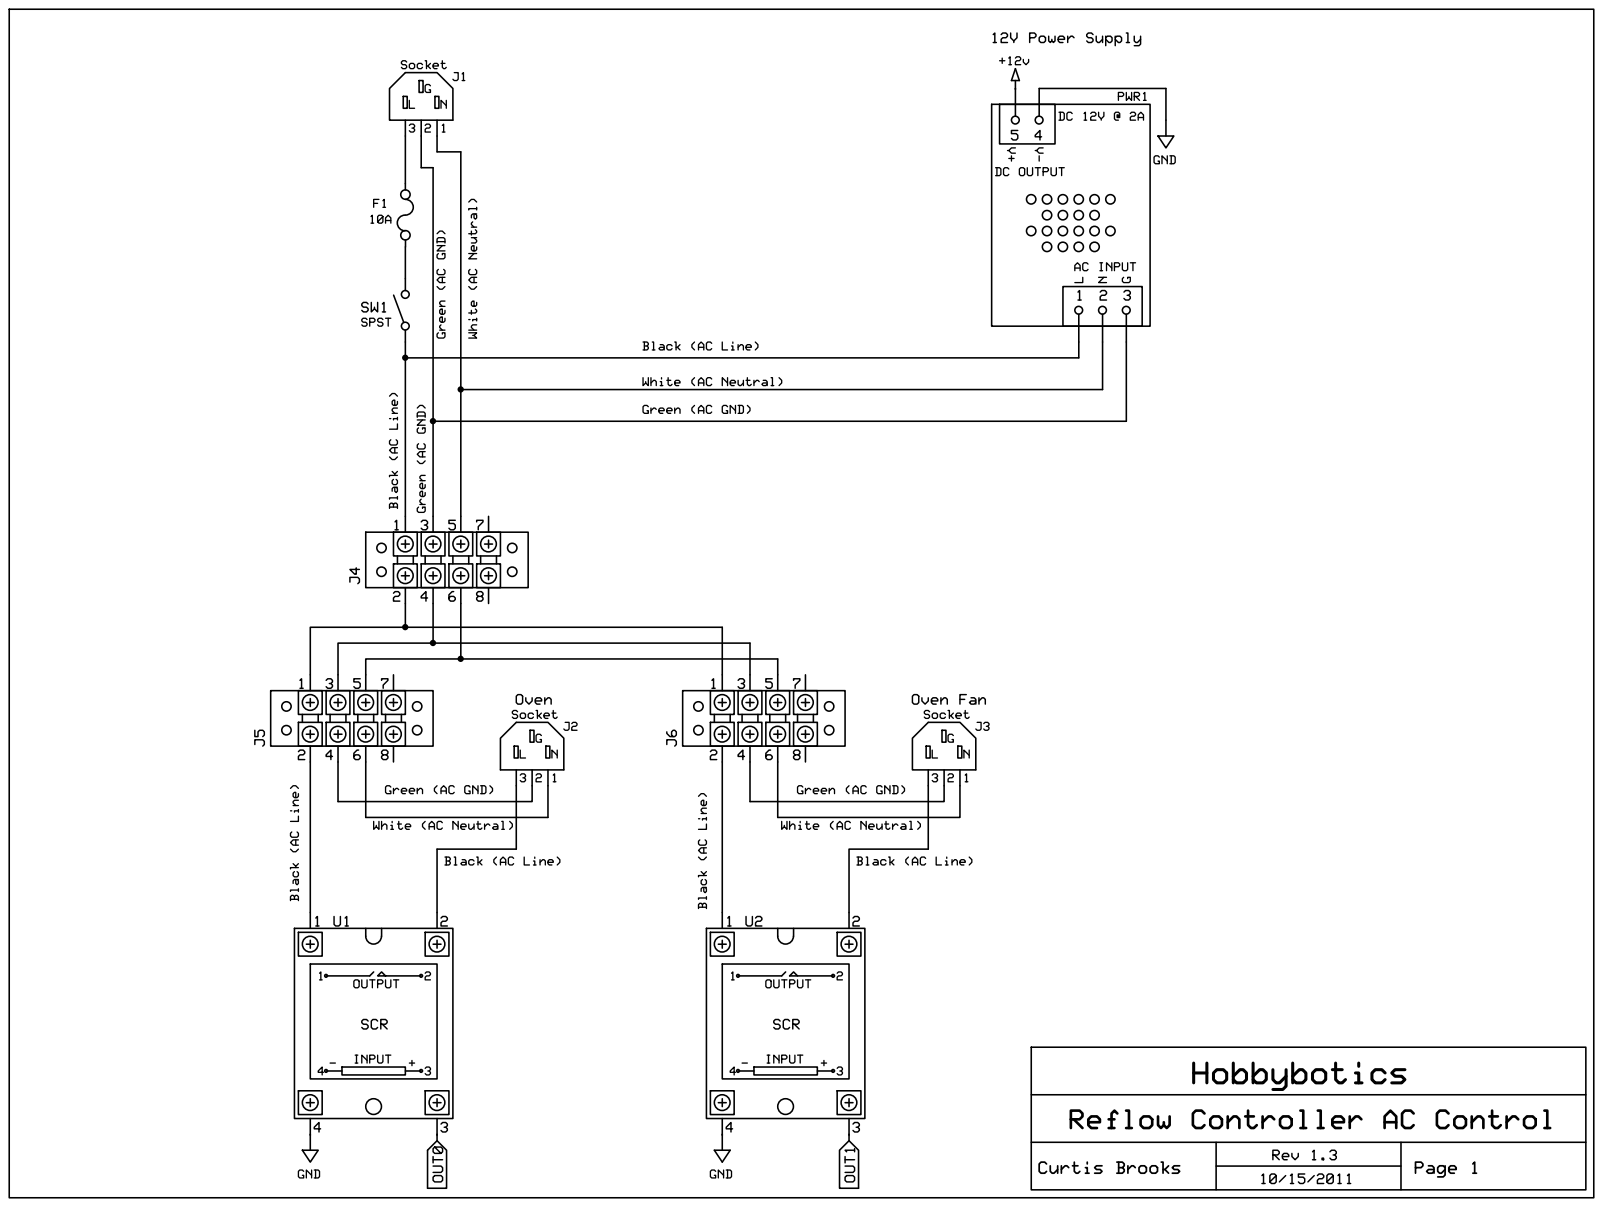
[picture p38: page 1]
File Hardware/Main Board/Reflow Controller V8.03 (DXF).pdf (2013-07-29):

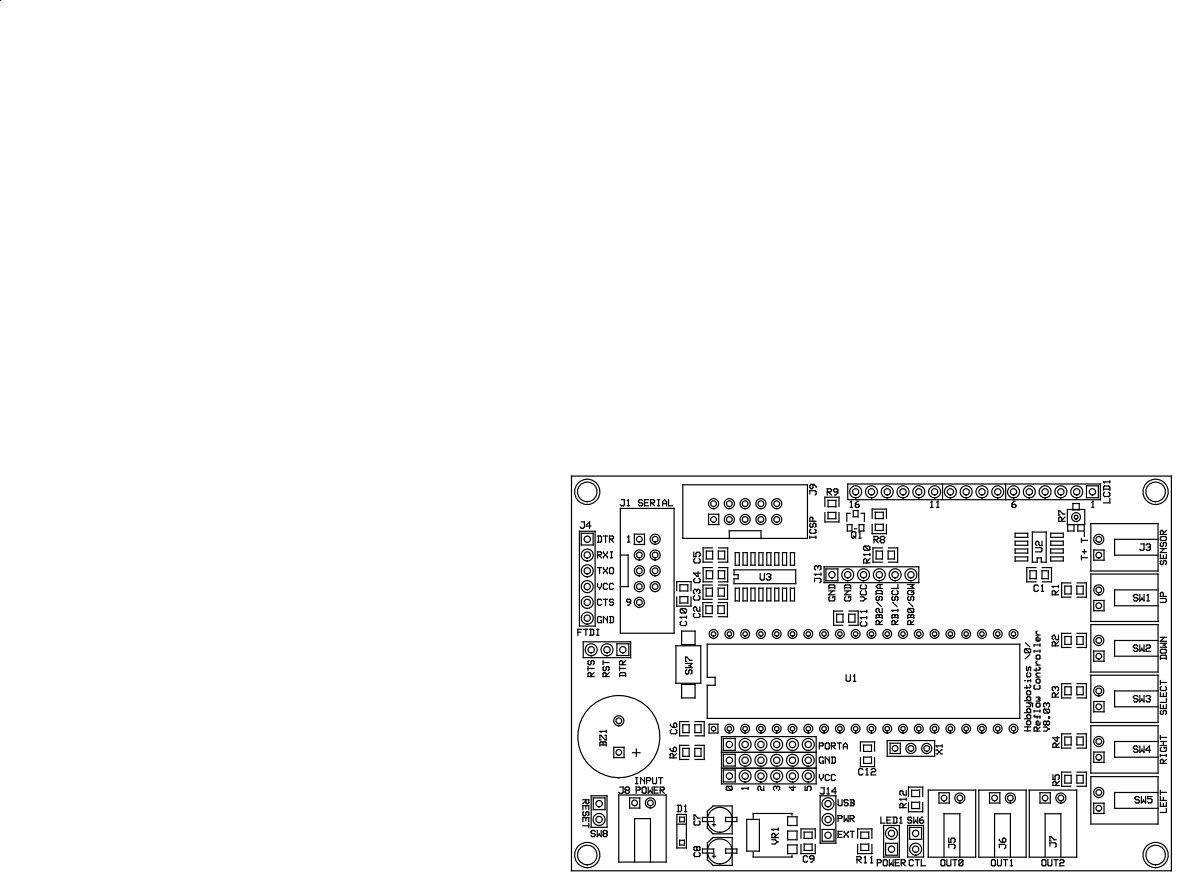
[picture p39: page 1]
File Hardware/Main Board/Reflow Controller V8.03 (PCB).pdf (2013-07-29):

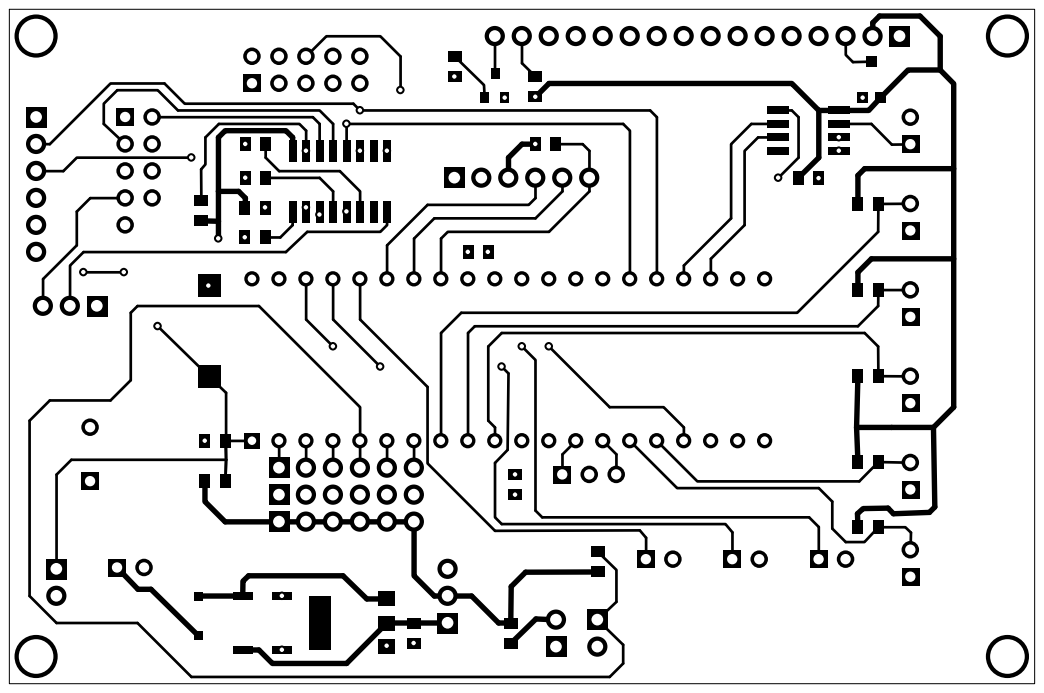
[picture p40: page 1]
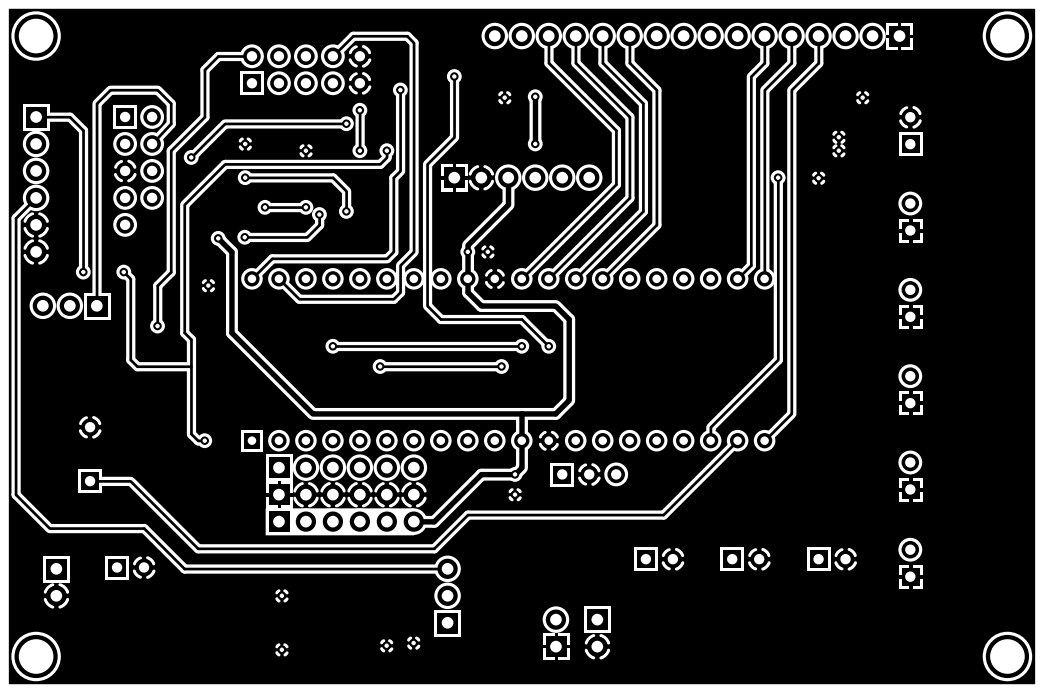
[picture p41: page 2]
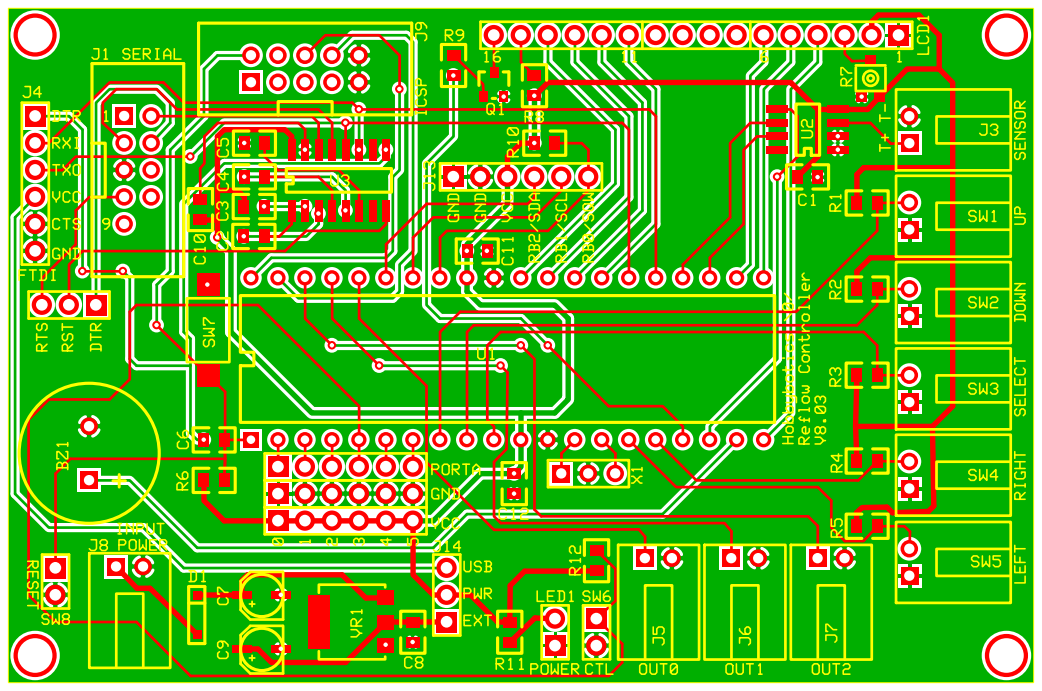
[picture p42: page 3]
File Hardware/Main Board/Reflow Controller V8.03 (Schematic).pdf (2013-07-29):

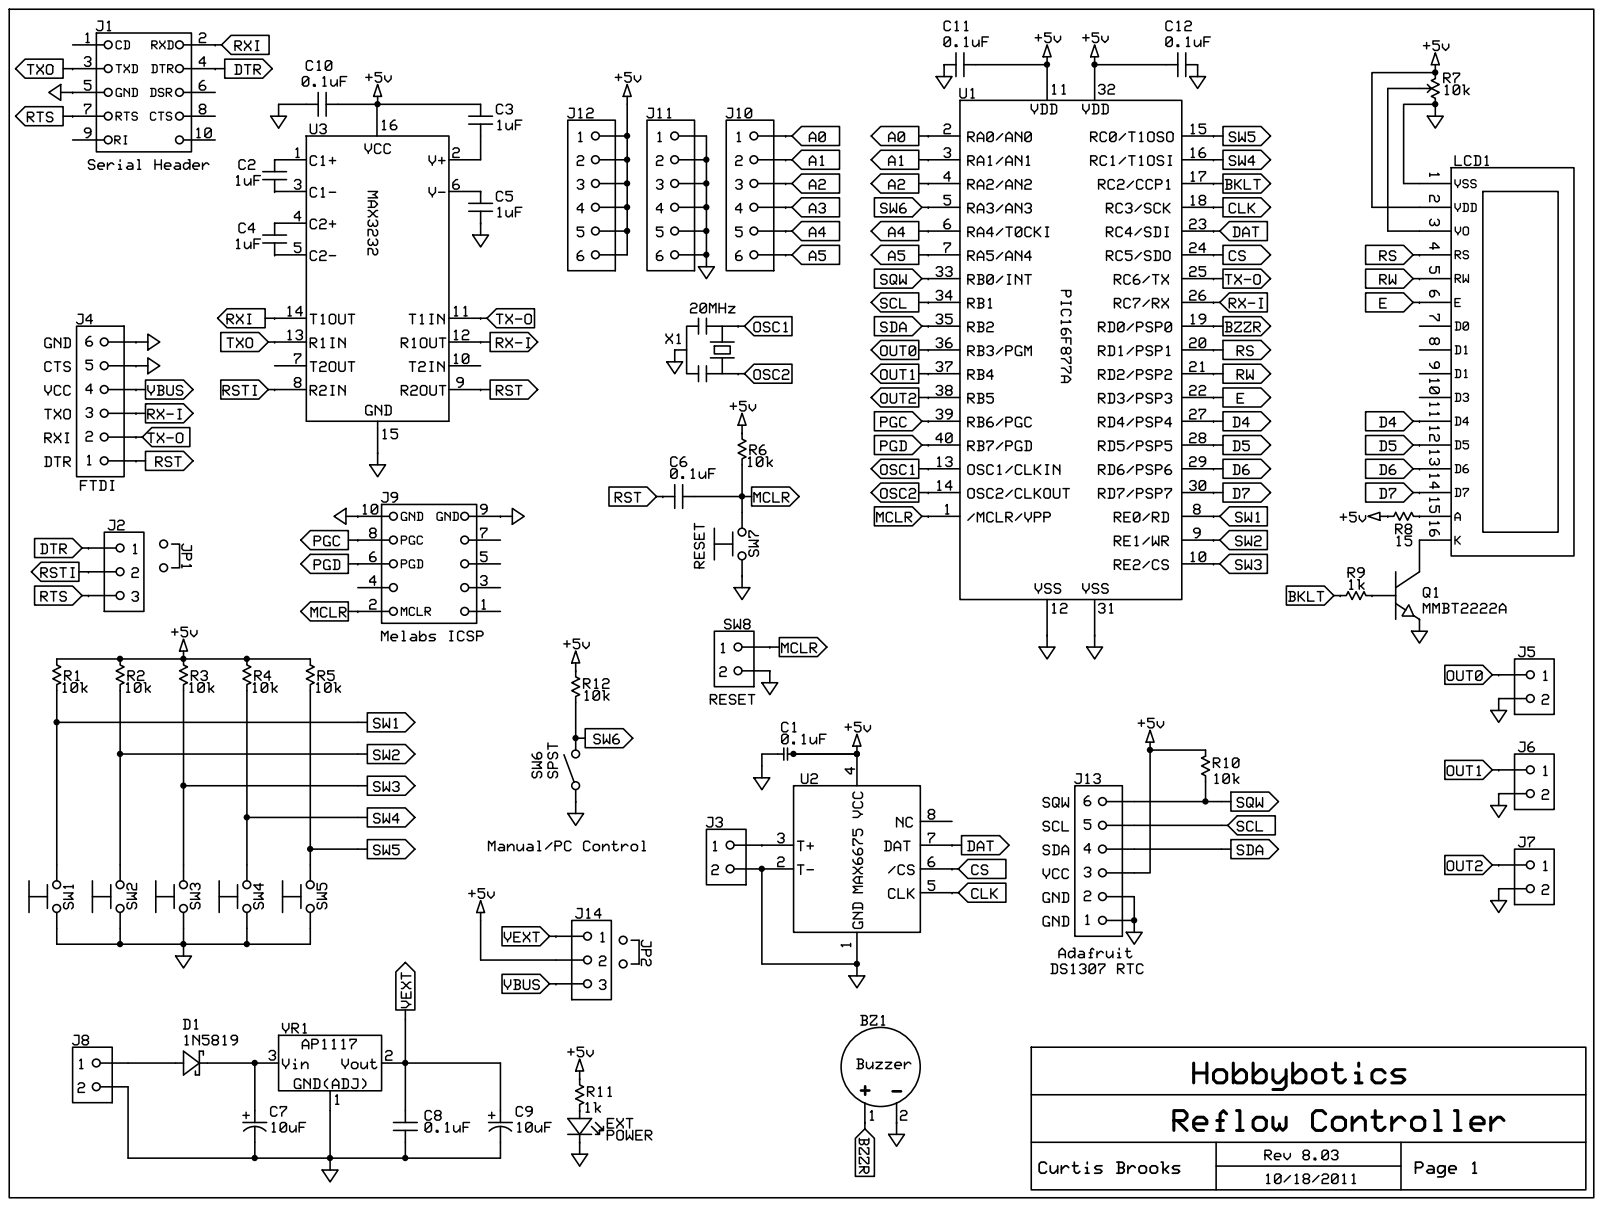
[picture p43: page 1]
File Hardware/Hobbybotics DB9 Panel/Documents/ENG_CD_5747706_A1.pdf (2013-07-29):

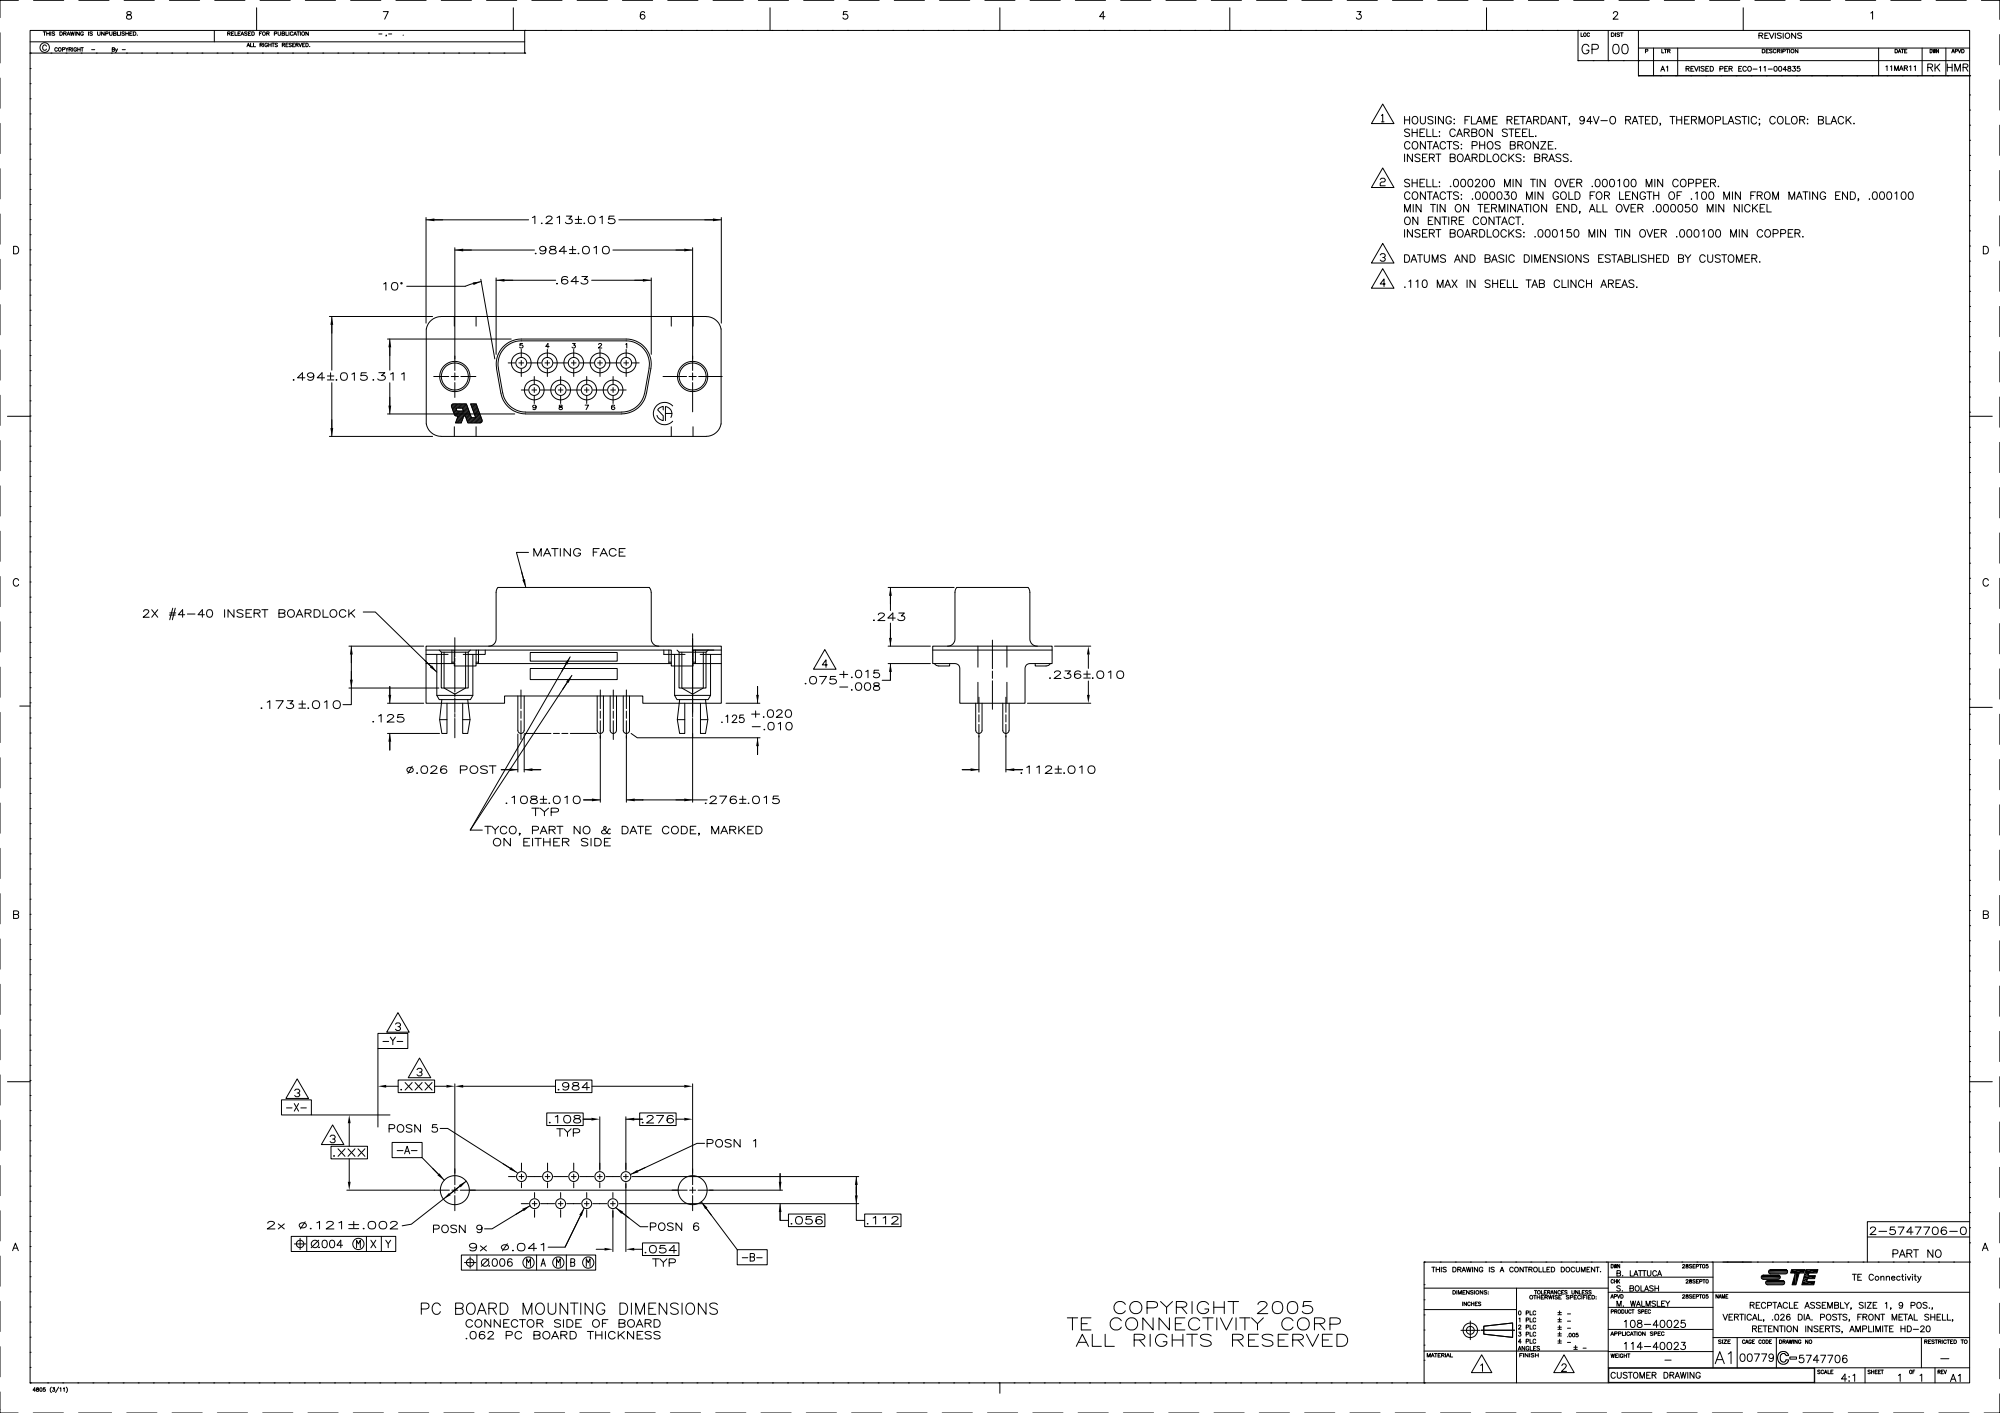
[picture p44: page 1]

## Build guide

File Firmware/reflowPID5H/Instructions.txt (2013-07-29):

1.  What to do if you get an, "Overwriting previous address contents." error or warning message while compiling the
    PicBasic Pro V2.60 project file:

    This error/warning is returned by PBP whenever the configuration fuses in the default inlude file for your chosen microcontroller are being overwritten.

    The simplist fix is to drop the following modified include file (16F877A.INC) into your 
    "C:\Program Files\PBP\" directory.  

	This file comments out the following two lines for the PIC16F877A device:

		;device  pic16F877A, xt_osc, wdt_on, lvp_off, protect_off

		;__config _XT_OSC & _WDT_ON & _LVP_OFF & _CP_OFF

2.  Make sure ReEnterPBP.bas, Elapsed_INT.bas, DT_INTS-14.bas and PIC16F877A.pbp are in the same project folder 
    as the reflowXX.pbp (XX is the revision number) file.

3.  There is a hex file in the project folder for those that do not want to compile the project.
